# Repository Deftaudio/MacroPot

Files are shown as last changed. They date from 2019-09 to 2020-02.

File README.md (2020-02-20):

# MacroPot

Deftaudio MacroPot is a single knob deeply programable MIDI controller with extended interface capabilities based around Teensy HW and Arduino programming model. It's designed to be the most compact Teensy3.2 MIDI implementation in a very dense packaging inside a rugged enclosure. You don't need to be experienced in Arduino programming, it comes with full featured firmware. However for experienced users can leverage an Open Source firmware available for your own modifications.
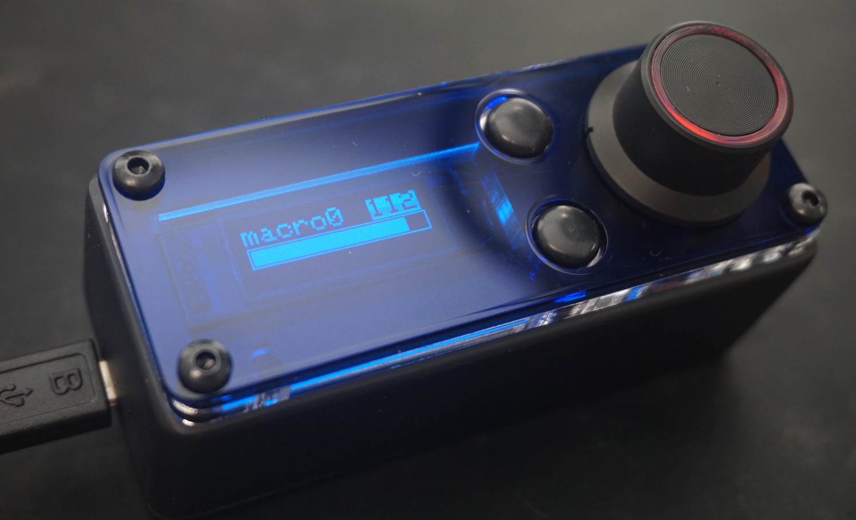
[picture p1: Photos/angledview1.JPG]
MacroPot assembled photo


### Introduction Video

https://youtu.be/noCOXES7csQ

### Hardware features:

- Rotary dual color (with brightness control) encoder with a push button

- OLED display for a visual feedback and preset information

- Up/Down buttons for a preset management

- 1 x MIDI Input (3.5mm TRS MIDI A or B)

- 3 x MIDI Output (3.5mm TRS MIDI A or B)

- USB MIDI Class compliant with 4 x MIDI devices under OS (1 physical port)

- 1 x Audio/CV/trigger/sync output (via PWM or DAC)

- Programmable activity LED

- Standalone operation from a power bank or power supply.

### Software features:

MacroPot is based around the idea of controlling multiple parameters at a time and quick switching between presets (macro). Within a current macro it’s possible to assign up to 5 simultaneous active controllers for transmit as well as a push button behavior. This allows to create layers or splits in values, assign controllers to different events, messages and MIDI ports, implement curves. MacroPot is also a 1x3 MIDI interface device with merging capability, which enables it at any place in the setup -- as a USB controller for any class compliant device or pass through HW MIDI input for your gear.

- **Number of Macros**:10

- **Number of controllers per Macro**:5

- **Controller parameters:**

	- USB output port number 1-4 to send a data out

	- MIDI port number 1-3 to send a data out

	- Type of the transmitted data: CC, Note, Program Change, Pitch Band (Synclavier mode), NRPN(future FW releases)

	- MIDI Channel 1-16

	- Programmable CC number, MIDI Note number or Program Change number

	- Controller range: Low value, High value

	- Controller mapping onto encoder position: Map start, Map end

	- Controller Curve for creating curves for CC messages

	- Programmable MIDI Note number for Note ON messages

- **Push Button parameters:**

	- USB output port number 1-4 to send a data out

	- MIDI port number 1-3 to send a data out

	- Type of the transmitted data: CC or Note

	- MIDI Channel 1-16

	- Programmable CC number or MIDI Note number

	- Programmable CC value or MIDI Note velocity

	- Different action behavior supported: Push button or Toggle(for Note)

- **MIDI Merge capability:** configurable per Macro HW MIDI input can pass through to any HW of 1-3 outputs

- **Assignable Macro name:** up to 7 characters on the display

- **Programming:** SysEx over USB

### Purchasing

MacroPot is an open project, you may decide to purchase a PCB only and source other parts by yourself with a BOM, get an electronic kit, a complete kit or go by pieces. There are multiple options for your level of experience and a budget.

- **MacroPot PCB only - $8**

- **MacroPot base electronic kit** (all electronics but Teensy 3.2): **- $38**

	- PCB

	- OLED

	- Encoder and a cap

	- Buttons and caps

	- Passive components - resistors, capacitors, diodes

	- Connectors - pin headers, 3.5mm TRS sockets

	- Dupont wires

- **MacroPot complete kit: - $68**

	- Base electronic kit

	- Teensy 3.2 (pre-programmed)

	- Enclosure *_(requires drilling and painting)_*

	- Acrylic panels

	- Rubber stands

	- Top screws

	- Thermal pad (TIM)
	
	- USB cable

- **MacroPot assembled unit - $118**

- **Spares:**

	- Acrylic Panels - $10

	- Transparent encoder cap - $5

	- Custom 3.5 mm mini stereo to 5 pin DIN MIDI breakout cable (male or female, Type A or Type B) - $7

#### **Available at:**

Tindie: https://www.tindie.com/stores/deftaudio/

- https://www.tindie.com/products/deftaudio/macropot-deeply-programmable-midi-controller-kit/

eBay: https://www.ebay.com/sch/ktracker_rus/m.html

- https://www.ebay.com/itm/333318502019
- https://www.ebay.com/itm/333318503584
- https://www.ebay.com/itm/333318504255
- https://www.ebay.com/itm/333318504975
- https://www.ebay.com/itm/333319417566
- https://www.ebay.com/itm/333319422143

### BOM list

https://docs.google.com/spreadsheets/d/15D16pYKxWzvwlihMUm6H49rWIW-DiubtF_ozgL0KMLI/edit?usp=sharing

### Assembly Guide

MacroPot is modular, you may decide that for particular project you don’t need all three MIDI outputs, or MIDI input, or Analog output and so you can omit some components. The schematic is open, you’re free to do that. Complete assembly process is documented in the guide and includes soldering, mechanical and programming steps.

https://docs.google.com/document/d/1nHQZJlmbKfMoiNE-2jQ2WAEOWn6yFhDtXKQVzbqB8Ts/edit?usp=sharing

**ASSEMBLY VIDEO:**

https://youtu.be/n0h99QKWodY

### Programming Guide

MacroPot is programmable over SysEX messages. There is no GUI editor currently, instead you just send a raw SysEx command with your favourite tool. I highly recommend cross-platform command line SendMIDI utility by Geert Bevin https://github.com/gbevin/SendMIDI but other tools, such as MIDIOX will work too.

SysEx programming may look confusing in a first place, in fact, you got great documentation to support your learning. You'll learn everything from here:

https://docs.google.com/document/d/1nPIYxyJ24XFE5UrgwzTidY-a2B3J3utPwMfMKG4Hb1w/edit?usp=sharing

**PROGRAMMING VIDEO:**

https://youtu.be/COOzS5v5v0I

**Synclavier Mode:**

https://youtu.be/EoEbT5Iu1uM

Andrei Kudryavtsev, Deftaudio 2008-2019.

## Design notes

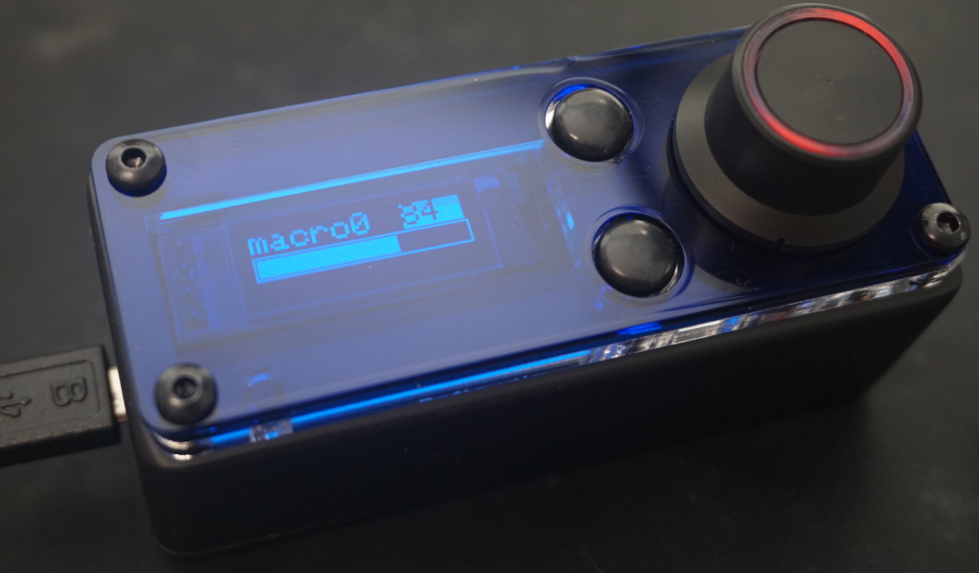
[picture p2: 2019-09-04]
Photos/angledview3.JPG

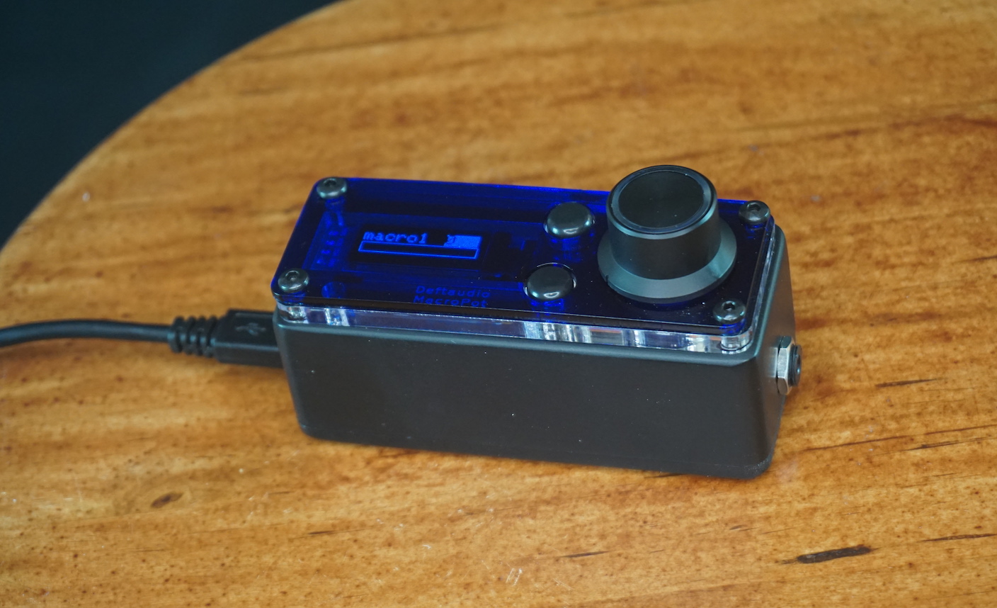
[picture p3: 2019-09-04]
Photos/faceview.JPG

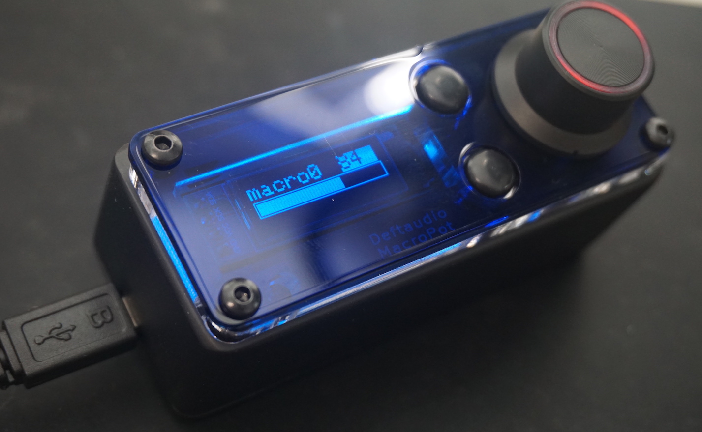
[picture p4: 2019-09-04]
Photos/angledview2.JPG

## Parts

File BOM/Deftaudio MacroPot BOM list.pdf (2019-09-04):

Deftaudio MacroPot BOM:
| P/N | Order from | Notes
U1 | 6N138 | https://www.mouser.com/ProductDetail/Broadcom-Avago/6N138-000E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 DIP package, install without a socket
U2 | Teensy 3.2 | https://www.pjrc.com/store/teensy32.html
D1 | 1N4148 | https://www.mouser.com/ProductDetail/ON-Semiconductor-Fairchild/1N4148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
D2 | 3mm LED | https://www.mouser.com/ProductDetail/Cree-Inc/C4SMA-BGF-CR2T3451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 Any standard 3mm LED, blue or other color
C1 | 10uf | https://www.mouser.com/ProductDetail/Nichicon/UVR1C100MDD1TD?qs=sGAEpiMZZMtZ1n0r9vR22WEPlYsslMWCGKrYlt2ZoWs%3D PWM audio output circuit, not required in case of DAC output
C2 | 103 0.01uf | https://www.mouser.com/ProductDetail/TDK/FG18X7R1H103KNT06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 PWM audio output circuit, not required in case of DAC output
C4, C5 | 103 0.01uf | https://www.mouser.com/ProductDetail/TDK/FG18X7R1H103KNT06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
C3 | 104 0.1uf | https://www.mouser.com/ProductDetail/TDK/FG16C0G1H104JNT06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
R1, R12, R17, R18 | 220 | https://www.mouser.com/ProductDetail/Xicon/271-220-RC?qs=t5KXG5YhMrJ%2F41luRETe6w%3D%3D
R2 | 100k | https://www.mouser.com/ProductDetail/Xicon/271-100K-RC?qs=sGAEpiMZZMu61qfTUdNhG8NgXDhdnsPdRkeci6KEHFY%3D PWM audio output circuit, not required in case of DAC output
R3 | 475 | https://www.mouser.com/ProductDetail/Xicon/271-475-RC?qs=sGAEpiMZZMu61qfTUdNhG3nVXymzmnYBdcdSbR9Z6RY%3D PWM audio output circuit, not required in case of DAC output
R4 | 127 | https://www.mouser.com/ProductDetail/Xicon/271-127-RC?qs=sGAEpiMZZMu61qfTUdNhGycWKXxEhBp7m%2F845gb5024%3D PWM audio output circuit, not required in case of DAC output
R5, R6, R7, R8, R9, R10 | 47 | https://www.mouser.com/ProductDetail/Xicon/271-47-RC?qs=sGAEpiMZZMu61qfTUdNhG%2Fx58qVkkJBr38p6bJPqRbo%3D
R11 | 470 | https://www.mouser.com/ProductDetail/Xicon/271-470-RC?qs=sGAEpiMZZMu61qfTUdNhG8zTzhjuYKP4eg8KQe8i%252Bpo%3D
R13, R14, R15, R16 | 10k | https://www.mouser.com/ProductDetail/Xicon/271-10K-RC?qs=sGAEpiMZZMu61qfTUdNhG%2FNICg4NOtz51bQLKR8aMJE%3D
Encoder with a switch | PEL12D-4226G-S2024 | https://www.mouser.com/ProductDetail/652-PEL12D4226GS2024 Burns dual color encoder
Encoder transparent cap | N/A | https://www.aliexpress.com/item/1652540985.html?spm=a2g0s.9042311.0.0.27424c4dnusFbH D-shaft type needed
OLED | 0.91" white/blue OLED 128X32 | https://www.ebay.com/itm/0-91-inch-128x32-IIC-I2C-Blue-OLED-Display-Module-DC3-3V-5V-128-32-Arduino/322536659354 Be careful, some OLED modules require longer init at least delay(1500)
Pin headers | 2.54mm pitch | https://www.ebay.com/itm/10-Pair-Male-Female-40Pin-2-54mm-Header-Socket-Single-Row-Strip-PCB-Connector-Us/153478821543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 Male and female, cut to the size where need
SW1, SW2 | push buttons | https://www.aliexpress.com/item/32804050454.html?spm=a2g0s.9042311.0.0.27424c4dVGao3M Square button with a round plastic cap
3.5mm jack | N/A | https://www.aliexpress.com/item/32954185700.html?spm=a2g0s.9042311.0.0.27424c4dnusFbH Plastic case with a metal screw
2 pin Dupont cable | N/A | https://www.aliexpress.com/item/32425641933.html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,searchweb201602_1,searchweb201603_52 You can cut them in half or assemble your own 2-pin cable with a separate headers
Enclosure | N/A | https://www.ebay.com/itm/1590A-Effects-Pedal-Aluminum-Stomp-Box-Enclosure-for-Musical-Instrument-Cases-WU/193045848734 Aluminum Stomp Box 9.2*3.8*3.2cm. Drilling and painting are required
Top acrylic panels | N/A | https://www.tindie.com/ | You can order from Tindie or make your own, design is open
PCB | N/A | https://www.tindie.com/

*eBay and Aliexpress links are for refference only. Pick your preferable supplier.

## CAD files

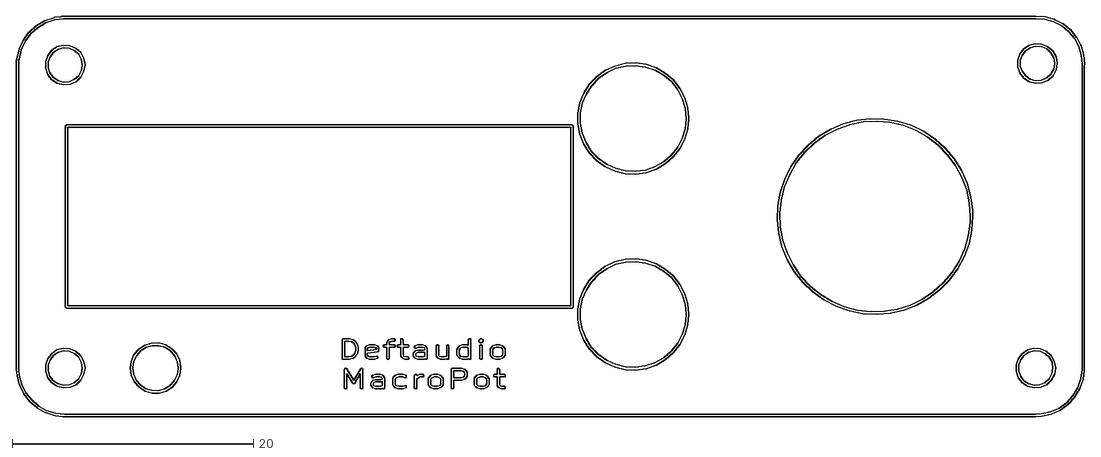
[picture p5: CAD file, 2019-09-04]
Acrylic panels/Middle layer/MacroPot-middle_4mm_clear_name.dxf
88.6 x 33.2

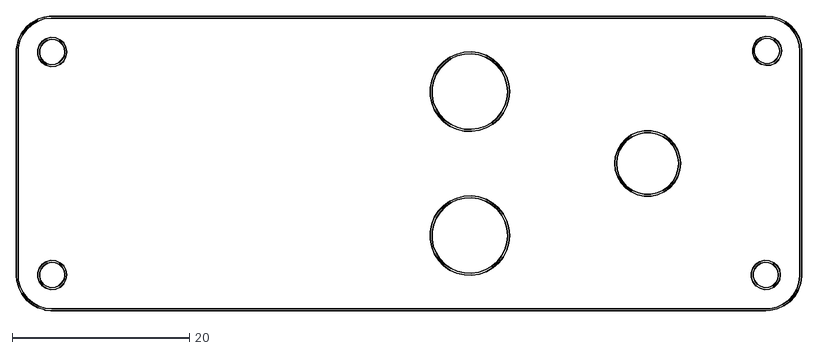
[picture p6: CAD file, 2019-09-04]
Acrylic panels/Top layer/MacroPot-top_1mm_blue.dxf
88.6 x 33.2

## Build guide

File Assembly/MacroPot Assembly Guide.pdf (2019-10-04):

# MacroPot Assembly Guide

The most recent version of this document is located here: https://docs.google.com/document/d/1nHQZJlmbKfMoiNE-2jQ2WAEOWn6yFhDtXKQVzbqB8Ts

MacroPot assembly process consists of three main steps. Electrical work - soldering all components, mechanical -
drilling an enclosure and painting, and initial firmware
initialization.
It may take upto an hour to finish the assembly (not counting a paint to dry) but depends on your level of experience. It’s
recommended that you solder a PCB first, and so you can test
the unit before assembling into the enclosure.

There is also a video version of this guide: https://youtu.be/n0h99QKWodY
Assembling a PCB.

This is a step where you can save some time, if you don’t use some of MacroPot functionality. For instance, you’re not planning to use PWM audio output or you don’t need all HW MIDI ports. You just don’t populate those parts and leave it empty.

Here are the components you may consider optional:
PWM audio output | R2, R3, R4, C1, C2, J2
HW MIDI input | R1, R11, D1, U1, C3, J1
HW MIDI output 1 | R5, R6, J3
HW MIDI output 2 | R9, R10, J5
HW MIDI output 3 | R7, R8, J4

Overall sequence doesn’t matter much, however, here are some recommendations to simplify the process, so soldering can be more convenient:

Andrei Kudryavtsev, Deftaudio 2008-2019.

1. Get familiar with the board design fist. Here are the front and back side of the board:

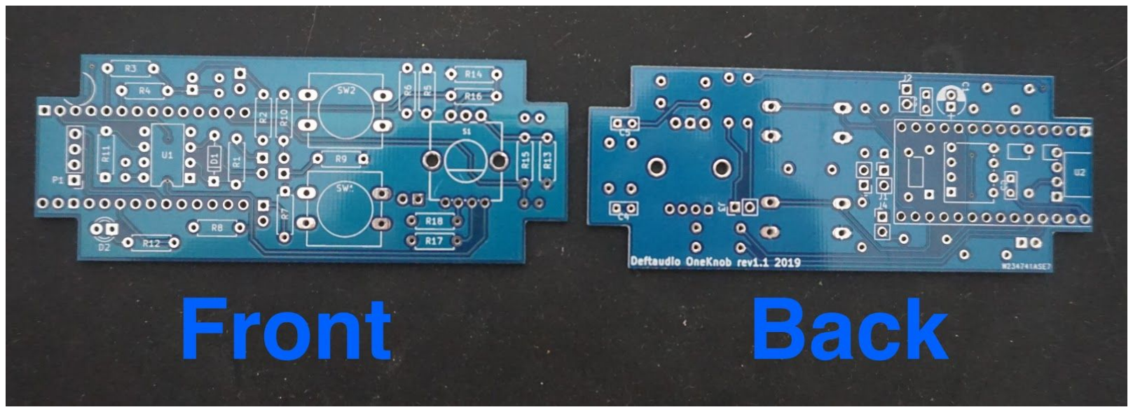
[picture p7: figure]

2. Decide on the functionality and components you need.
3. Start with soldering smaller parts first, such as resistors and diodes, so you lay the board on them and don’t need to hold them in a position.
4. Get to bigger components later, leave headers to the end.

### Soldering steps:

- Start with resistors on the front side and D1 diode. Those are:
D1 | 1N4148
R1, R12, R17, R18 | 220 ohm
R3(originally 475, 470 is Ok), R11 | 470 ohm
R13, R14, R15, R16 | 10k
R4(originally 127, 120 is Ok) | 120 ohm
R5, R6, R7, R8, R9, R10 | 47 ohm
R2 | 100k

- Add U1 (6N138) without socket (important) and two push buttons
- Flip the board over and populate capacitors on the back side. Those are:
C2, C4, C5 | 103 (0.01uf)
C3 | 104 (0.1uf)
C1 | 10uf

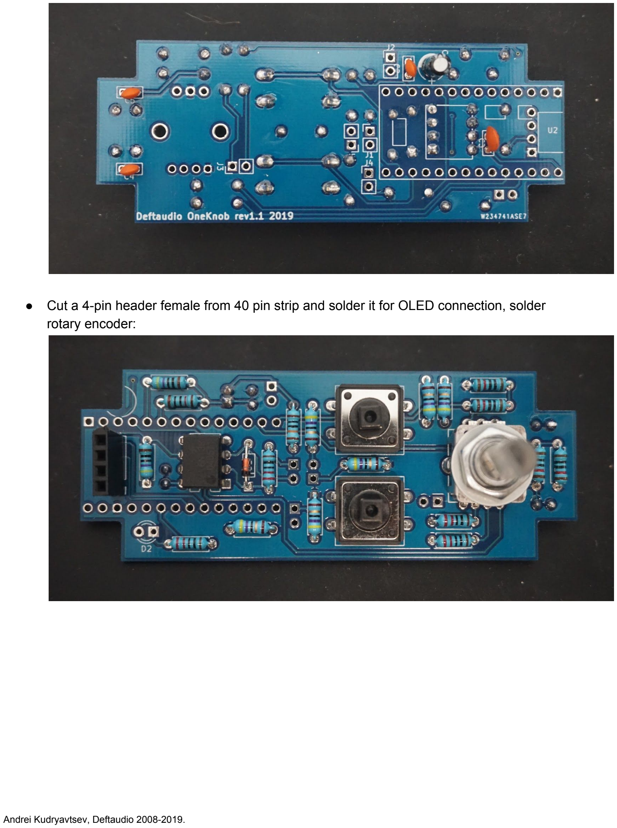
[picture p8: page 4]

- Cut a 4-pin header female from 40 pin strip and solder it for OLED connection, solder rotary encoder:

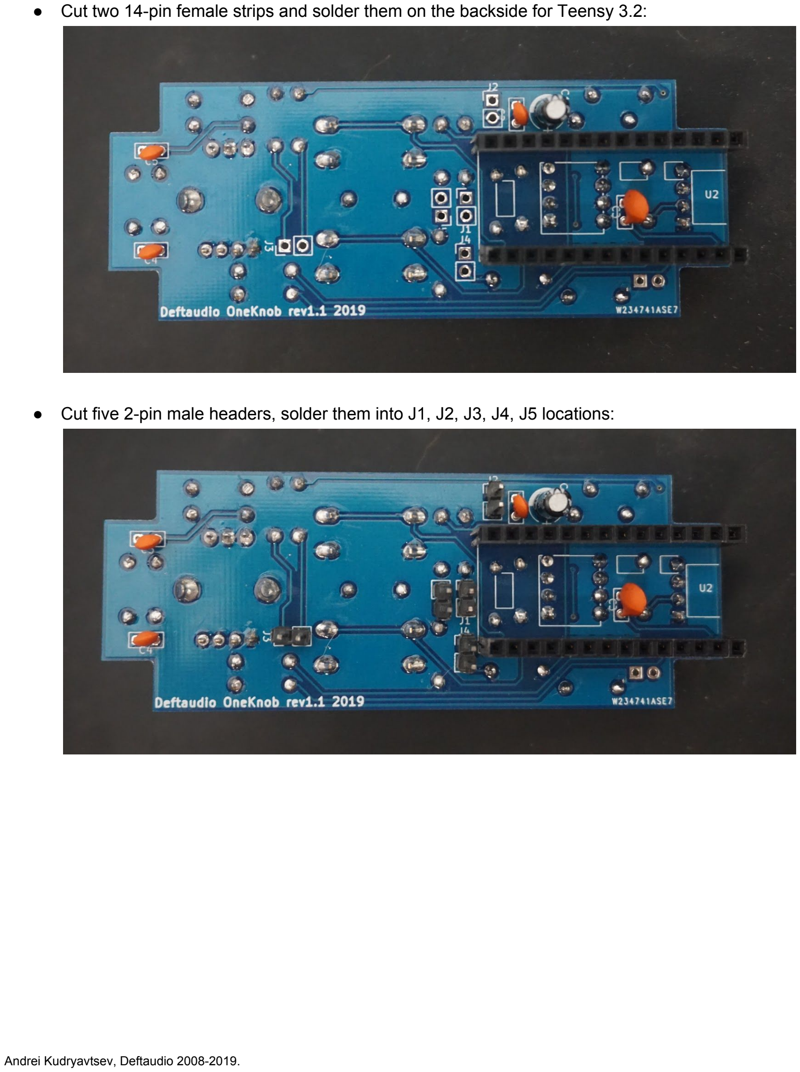
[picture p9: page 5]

- Cut two 14-pin female strips and solder them on the backside for Teensy 3.2:
- Cut five 2-pin male headers, solder them into J1, J2, J3, J4, J5 locations:

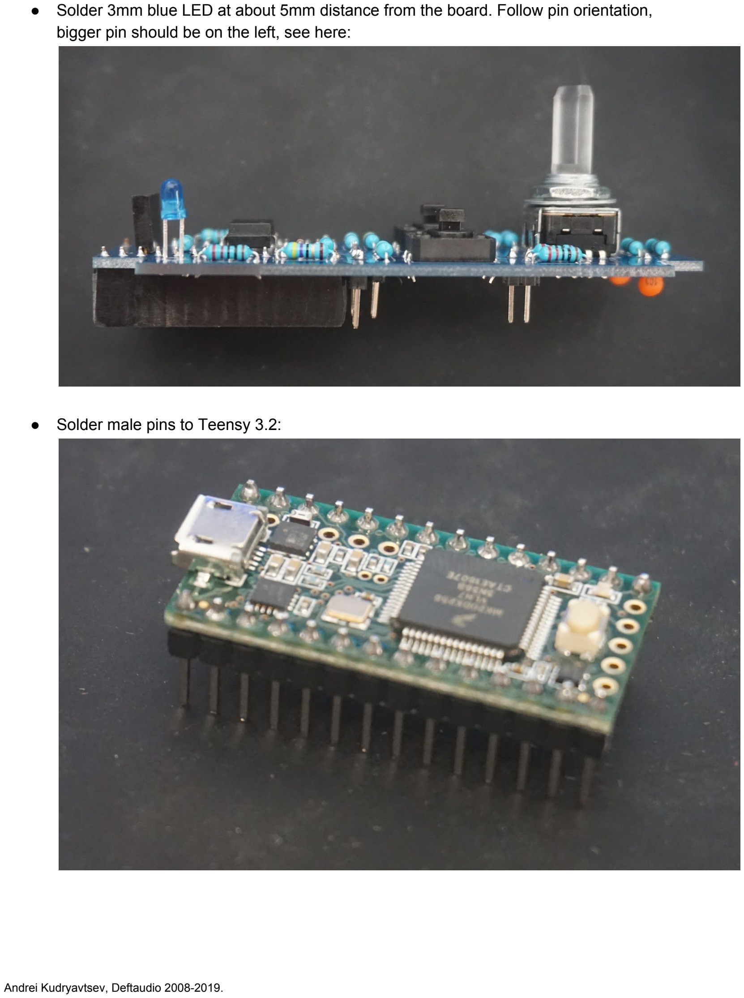
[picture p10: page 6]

- Solder 3mm blue LED at about 5mm distance from the board. Follow pin orientation, bigger pin should be on the left, see here:
- Solder male pins to Teensy 3.2:

Firmware initialization.

Right after you completed board soldering, it’s a good time to start MacroPot for the first time and make sure that at least basic functions are working fine. There are two stages in this process - updating firmware and loading default settings to Teensy’s EPROM.

### Updating a firmware from compiled *.hex file:

- If you’re experienced Arduino user, you may skip this part, it’s mainly for new users who are not familiar with Arduino programming or software development.
- *.hex file is a compiled binary, that you simply load to a Teensy board. That means, you don’t do any changes to the code by yourself, you just use what’s already available.
- While programming, Teensy can be assembled onto MacroPot board or just connected over USB without anything attached. This doesn’t matter. Obviously on the next power on it has to be attached to the board.

It’s important to understand that MacroPot saves macros and its state into nonvolatile memory (EPROM) of the Teensy controller. Main firmware image is only a program that runs on the controller. It doesn’t include any configuration parameters or pre-defined macroses. This is what needs to be configured after the firmware update. However, that’s also recommended to clean EPROM before updating main firmware, so, previous or garbage EPROM data won’t be used as macro configuration.

Steps:
- To start, download Teensy loader from official site: https://www.pjrc.com/teensy/loader.html
- Run it and drop eeprom_clear.hex firmware first from the MacroPot hex from the repository:
https://github.com/Deftaudio/MacroPot/blob/master/Firmware/eeprom_clear.hex
- Press button on Teensy and make sure loader app updated it.

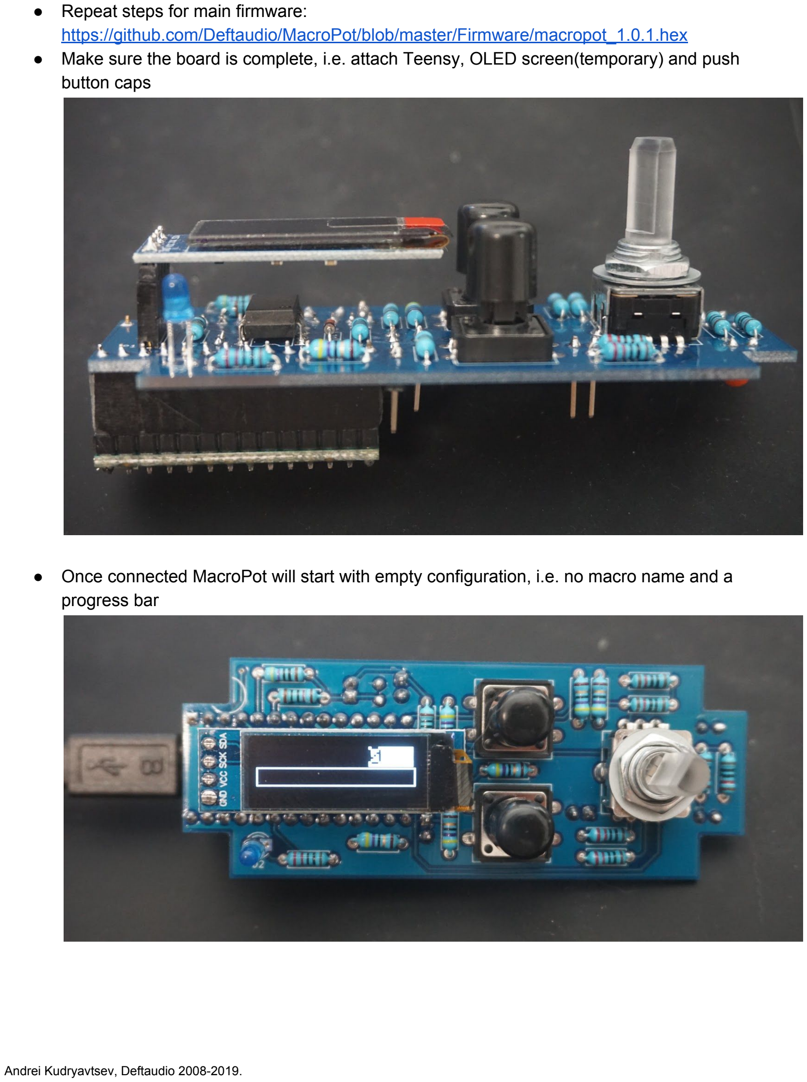
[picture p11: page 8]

- Repeat steps for main firmware: https://github.com/Deftaudio/MacroPot/blob/master/Firmware/macropot_1.0.1.hex
- Make sure the board is complete, i.e. attach Teensy, OLED screen(temporary) and push button caps
- Once connected MacroPot will start with empty configuration, i.e. no macro name and a progress bar

### Alternative: Updating a firmware from Arduino project:

- This step assumes that you take MacroPot source files, compile them and load to Teensy. It’s for experienced users how are willing to enhance MacroPot functions in future by contributing into the software development.
- Make sure you’re running latest Arduino version.
- Download and install Teensyduino: https://www.pjrc.com/teensy/td_download.html
- Open MacroPot project file.
- Set a controller to Teensy 3.2 in MIDIx4 mode.
- Set a running speed to 72Mhz, you don’t need to overclock Teensy for basic firmware.
- Compile and load eeprom_clear tutorial sketch following by the main firmware.

### Loading default macro configuration

MacroPot is deeply programmable controller over SysEx messages. However, to get you started, there are default scripts created to program its state. This minimizes your learning time, as default macroses designed to cover many common scenarios. Follow the download repository https://github.com/Deftaudio/MacroPot/tree/master/SysEx%20scripts you’ll find MS Windows and Mac OS X versions. They are designed to use cross-platform command line SendMIDI utility by Geert Bevin: https://github.com/gbevin/SendMIDI Just put a recent binary to the script directory first.

Here is an example of running SendMIDI under Windows,
- Run Command Line “cmd” and change a directory to the location of scripts:
- Connect MacroPot and execute “sendmidi list”. You’ll see all MIDI output devices connected to the system. As MacroPot has four virtual USB ports, there four separate devices below. You can use any of them for programming, but it’s easier to pick the first one due to a naming convention. Scripts do that by default.
- Press simultaneously Up and Down buttons on MacroPot controller, until “Sysex Mod” appears on the screen.
- Execute init.bat (Windows) or init.sh (OS X, don’t forget to make it executable first)

- Once script finishes, press Up button, now you should be able to see a default macro name:

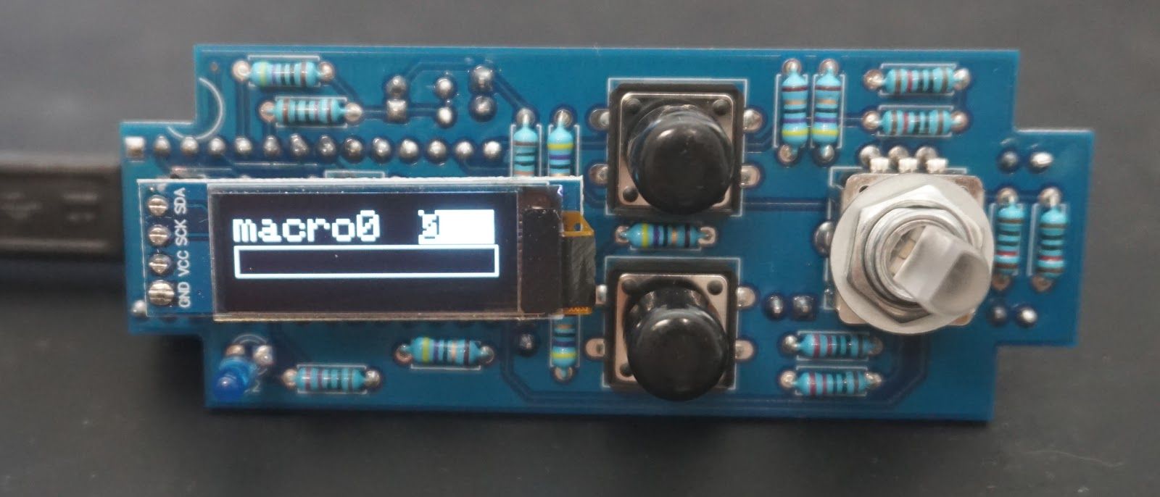
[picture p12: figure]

- At this point, you may run some basic tests, even without hardware MIDI ports connected. You may use MIDI OX or similar MIDI monitor sniffing USB MIDI traffic.

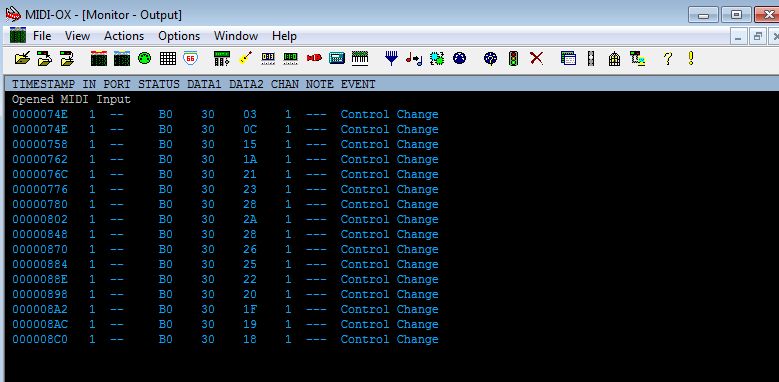
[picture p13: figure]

A note about TRS-DIN MIDI breakout cable.

At the time vendors decided to utilize TRS connectors for MIDI a common standard didn’t exist. So, every manufacturer went their own way, which basically introduced two standards, called Type A and Type B. Please,refer to MIDI.org article about that: https://www.midi.org/articles-old/updated-how-to-make-your-own-3-5mm-mini-stereo-trs-to-midi-5-pin-din-cables (https://www.midi.org/articles-old/updated-how-to-make-your-own-3-5mm-mini-stereo-trs-to-midi-5-pin-din-cables)

Type A assumes TRS tip is connected to Pin 5, and ring to Pin 4. While Type B specs has Pin 4 on a tip and ring on Pin 5. In both cases sleeve is the ground.

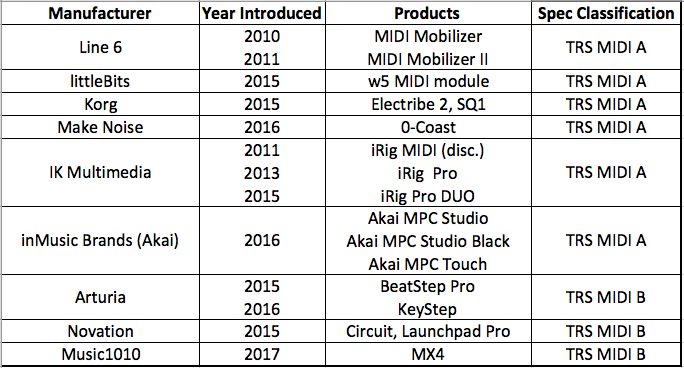
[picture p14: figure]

By the design MacroPot supports both types, all you need to do is to flip pin on a board header and so that changed tip/ring assignment. Ground pin is ignored, can be simply implemented by connecting it to the enclosure. Good news, that MIDI designed in a way, that even if you used the wrong polarity, this won’t burn the scheme. So, if port doesn’t work from the first attempt, flip the pin orientation and try again.

Connecting External Ports - MIDI and Audio.

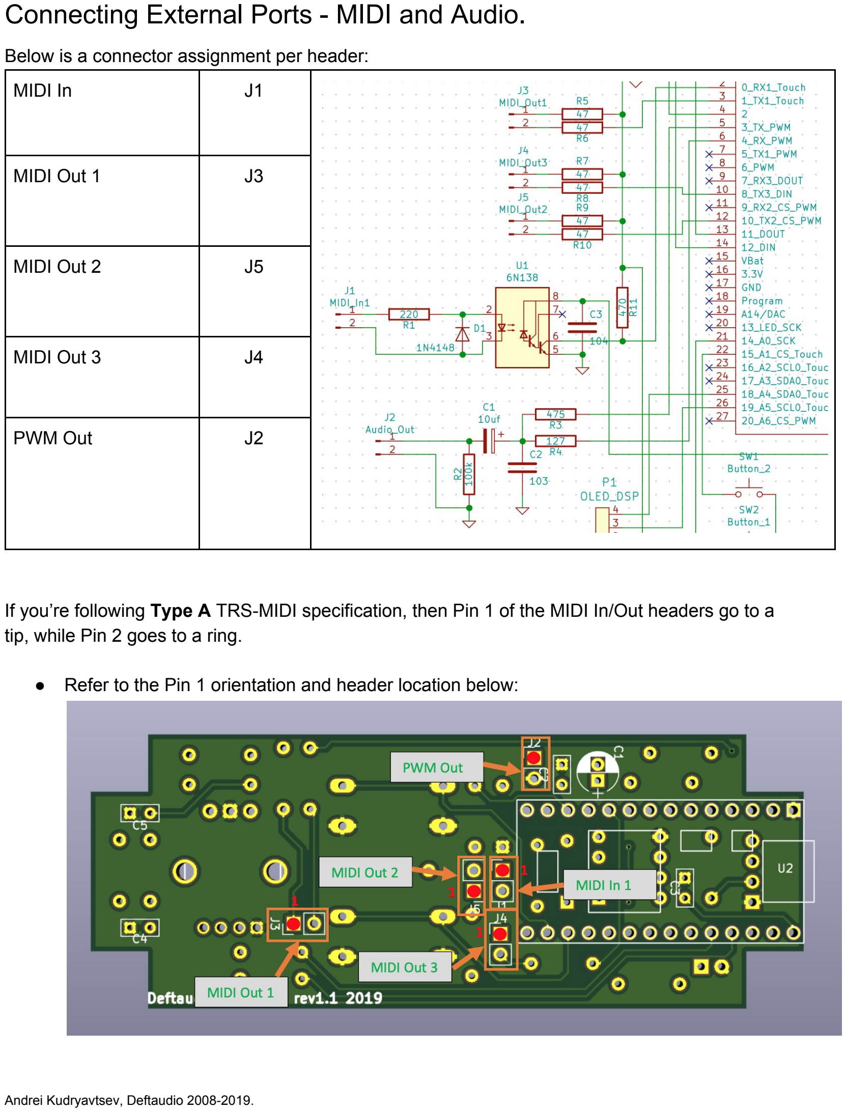
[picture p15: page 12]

Below is a connector assignment per header:
MIDI In | J1
MIDI Out 1 | J3
MIDI Out 2 | J5
MIDI Out 3 | J4
PWM Out | J2

If you’re following Type A TRS-MIDI specification, then Pin 1 of the MIDI In/Out headers go to a tip, while Pin 2 goes to a ring.

- Refer to the Pin 1 orientation and header location below:

- MIDI TRS socket orientation is shown below. On this connector type a ring is labeled #2 and tip is #3. Solder wires of different colors to differentiate them:

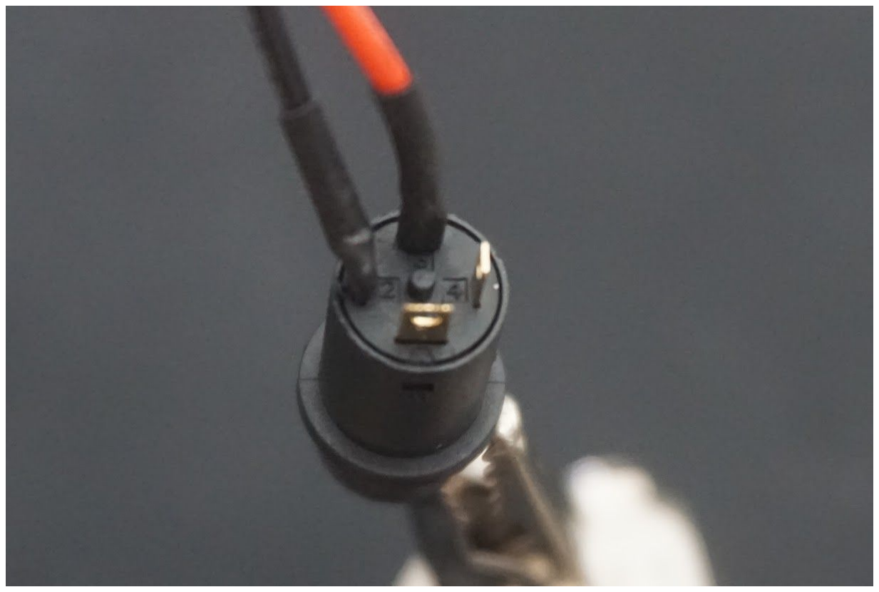
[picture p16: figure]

- So with that red wire means tip and black wire is for ring. Connect those accordingly to Type A or Type B specification to MacroPot headers.

Audio can be connected from two different places - PWM header output or DAC output. Those are differently programmed inside Teensy framework, you may prefer to use DAC output for better quality(12 bit) or even both of them together, if tip and ring pins utilized.
- In order to use DAC output you need to solder a wire directly to the pin shown below, as it’s not routed on the board to any headers.

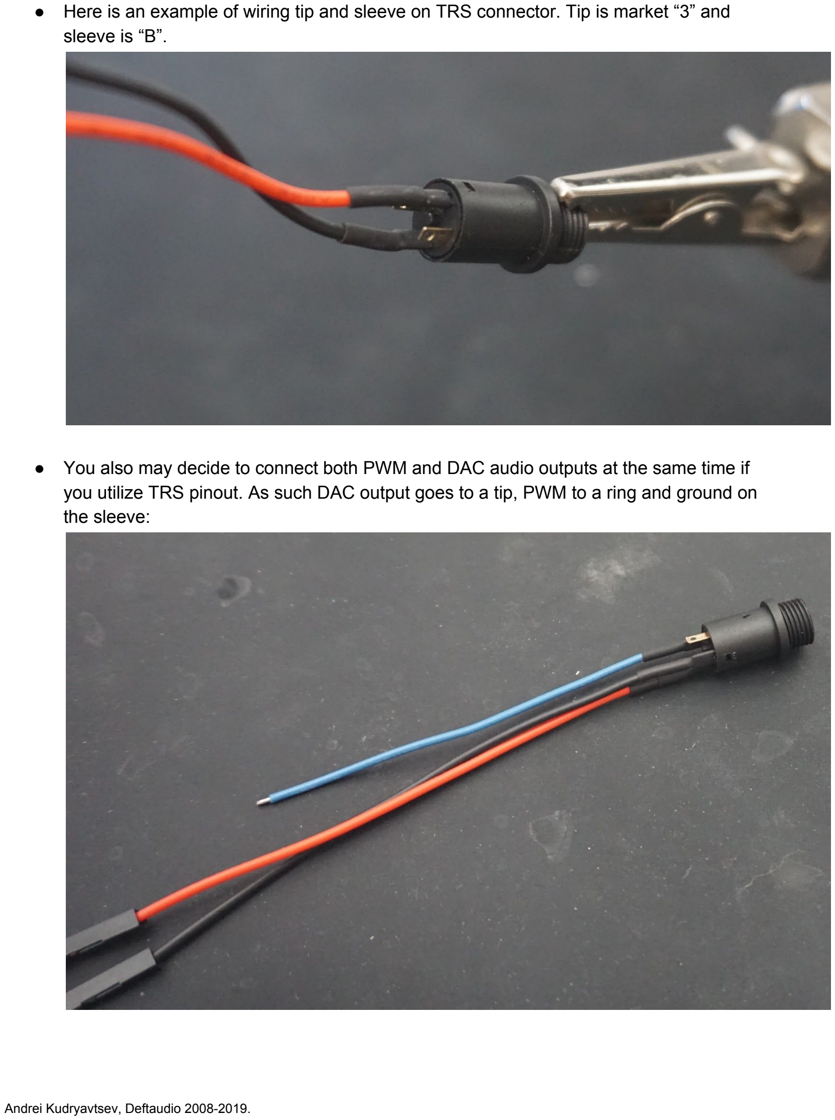
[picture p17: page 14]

- Here is an example of wiring tip and sleeve on TRS connector. Tip is market “3” and sleeve is “B”.
- You also may decide to connect both PWM and DAC audio outputs at the same time if you utilize TRS pinout. As such DAC output goes to a tip, PWM to a ring and ground on the sleeve:

Preparing an enclosure.

Preparing an enclosure requires drilling holes, making four threads and painting. You may decide to use a drill press or a hand drill. Core tool is highly recommended to make hole with a precision.
- Start by printing the draft label located here https://github.com/Deftaudio/MacroPot/blob/master/Acrylic%20panels/MacroPot-drill_alli gnment.pdf (https://github.com/Deftaudio/MacroPot/blob/master/Acrylic%20panels/MacroPot-drill_allignment.pdf) cutting it to the size and aligning to the enclosure:

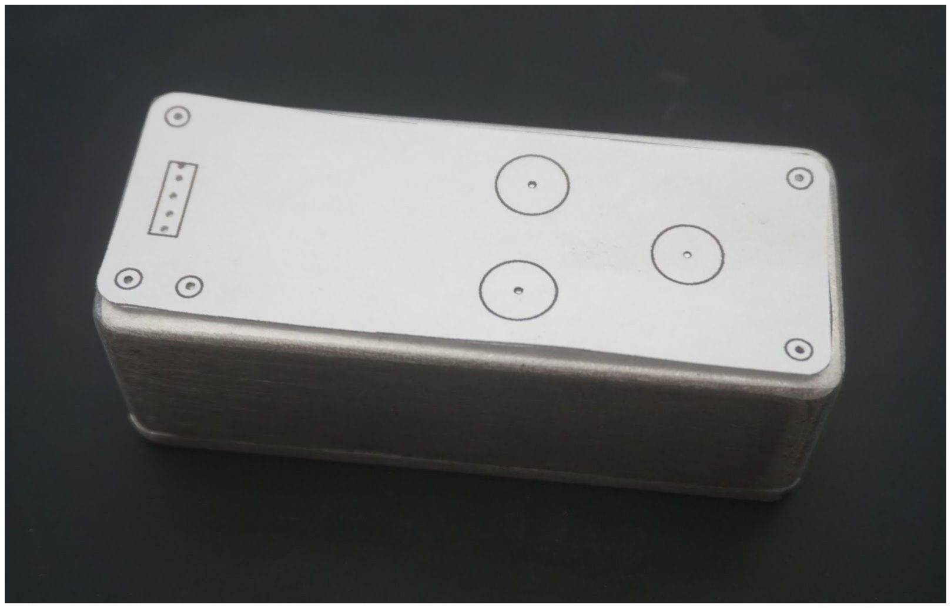
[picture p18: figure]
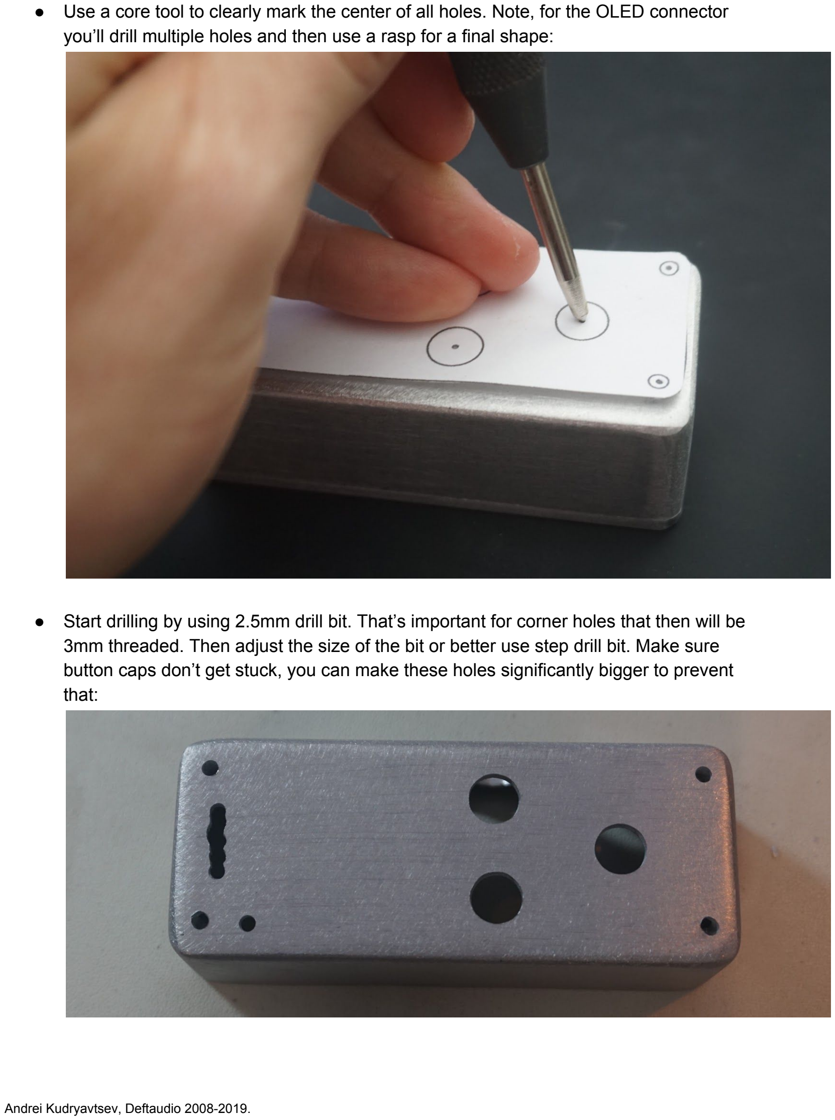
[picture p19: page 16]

- Use a core tool to clearly mark the center of all holes. Note, for the OLED connector you’ll drill multiple holes and then use a rasp for a final shape:
- Start drilling by using 2.5mm drill bit. That’s important for corner holes that then will be 3mm threaded. Then adjust the size of the bit or better use step drill bit. Make sure button caps don’t get stuck, you can make these holes significantly bigger to prevent that:

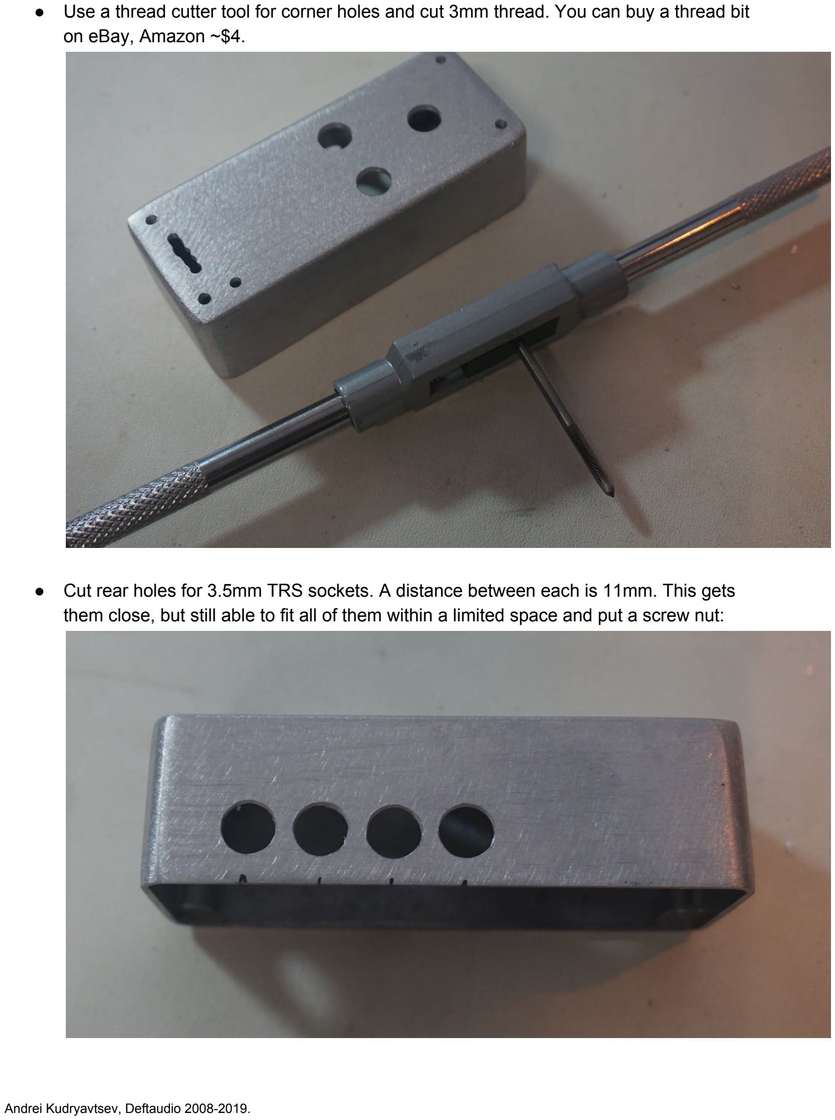
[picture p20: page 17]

- Use a thread cutter tool for corner holes and cut 3mm thread. You can buy a thread bit on eBay, Amazon ~$4.
- Cut rear holes for 3.5mm TRS sockets. A distance between each is 11mm. This gets them close, but still able to fit all of them within a limited space and put a screw nut:

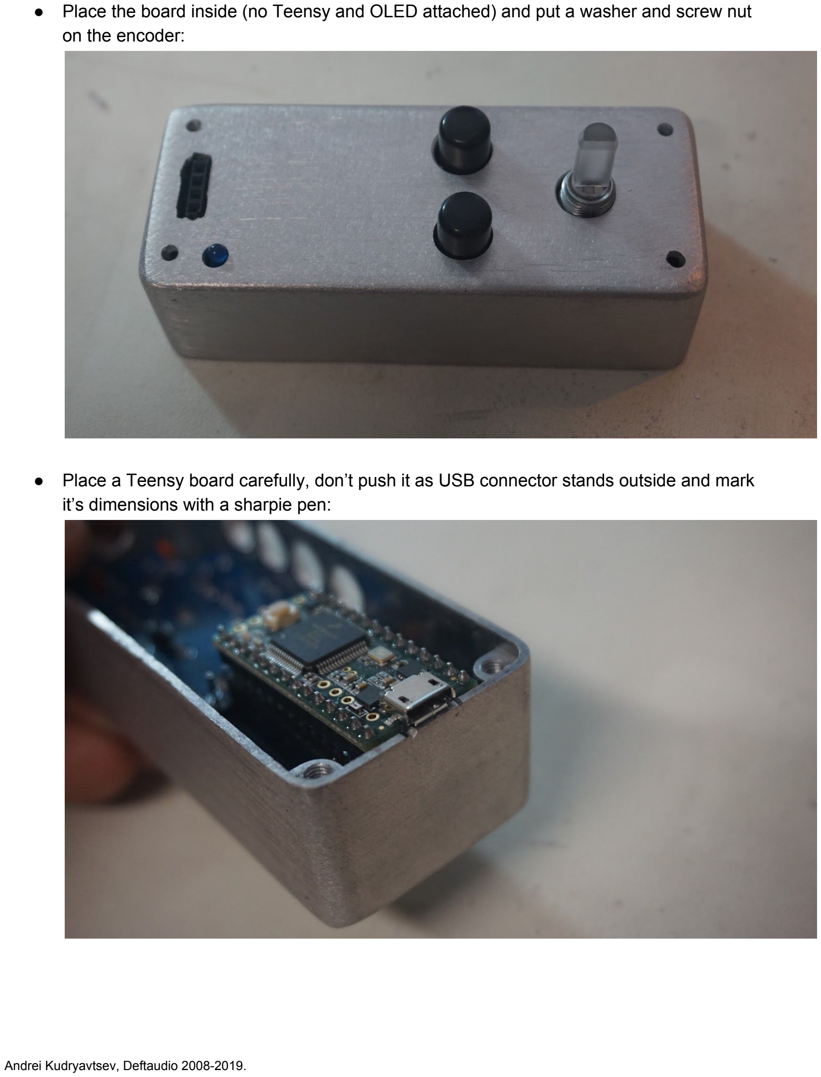
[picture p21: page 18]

- Place the board inside (no Teensy and OLED attached) and put a washer and screw nut on the encoder:
- Place a Teensy board carefully, don’t push it as USB connector stands outside and mark it’s dimensions with a sharpie pen:

- Use a rasp to get 2 mm inside, so microUSB connector stays flat.
- Place a bottom lid, mark with a sharpie tool again and use rasp to cut a piece there too:

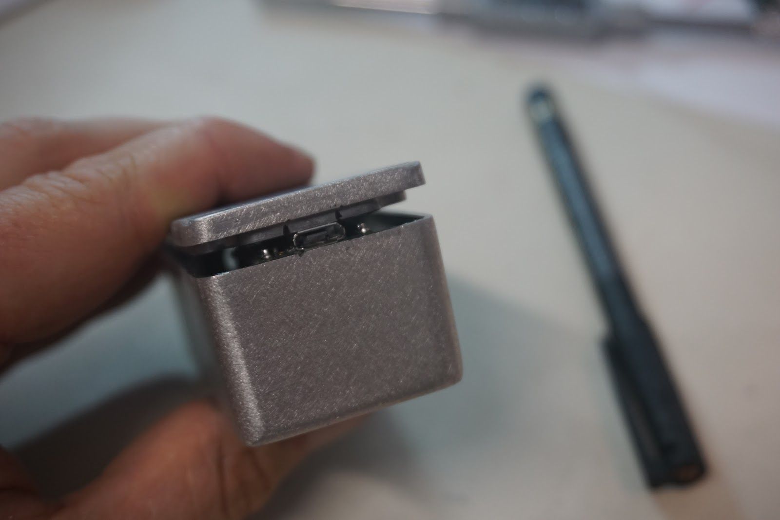
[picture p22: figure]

- Now it’s ready to be painted.

Final assembly.

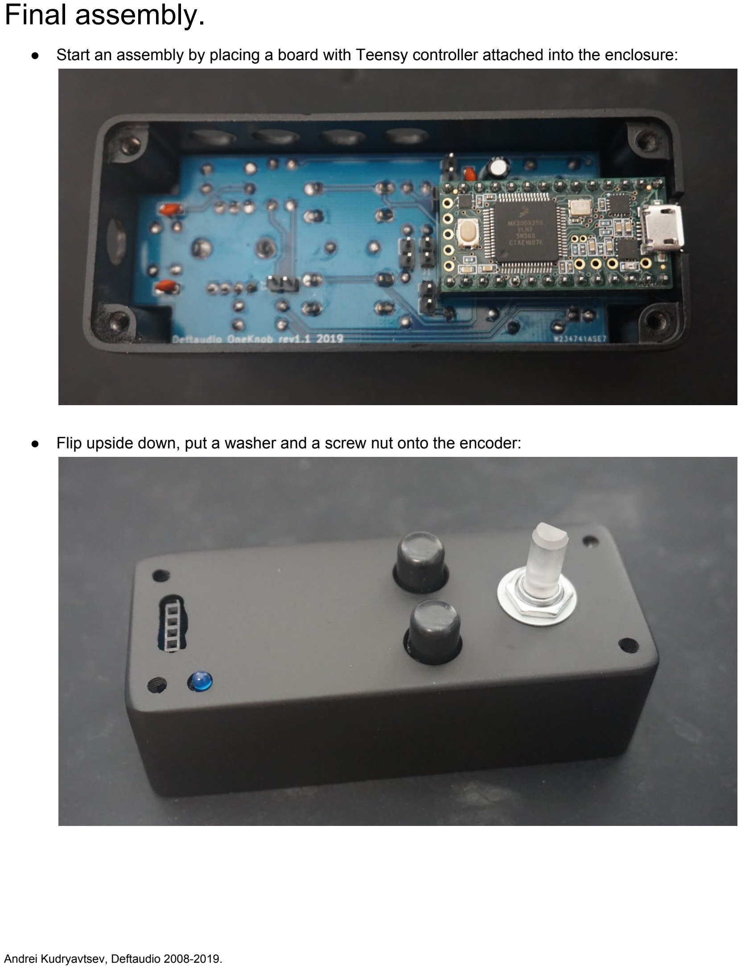
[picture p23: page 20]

- Start an assembly by placing a board with Teensy controller attached into the enclosure:
- Flip upside down, put a washer and a screw nut onto the encoder:

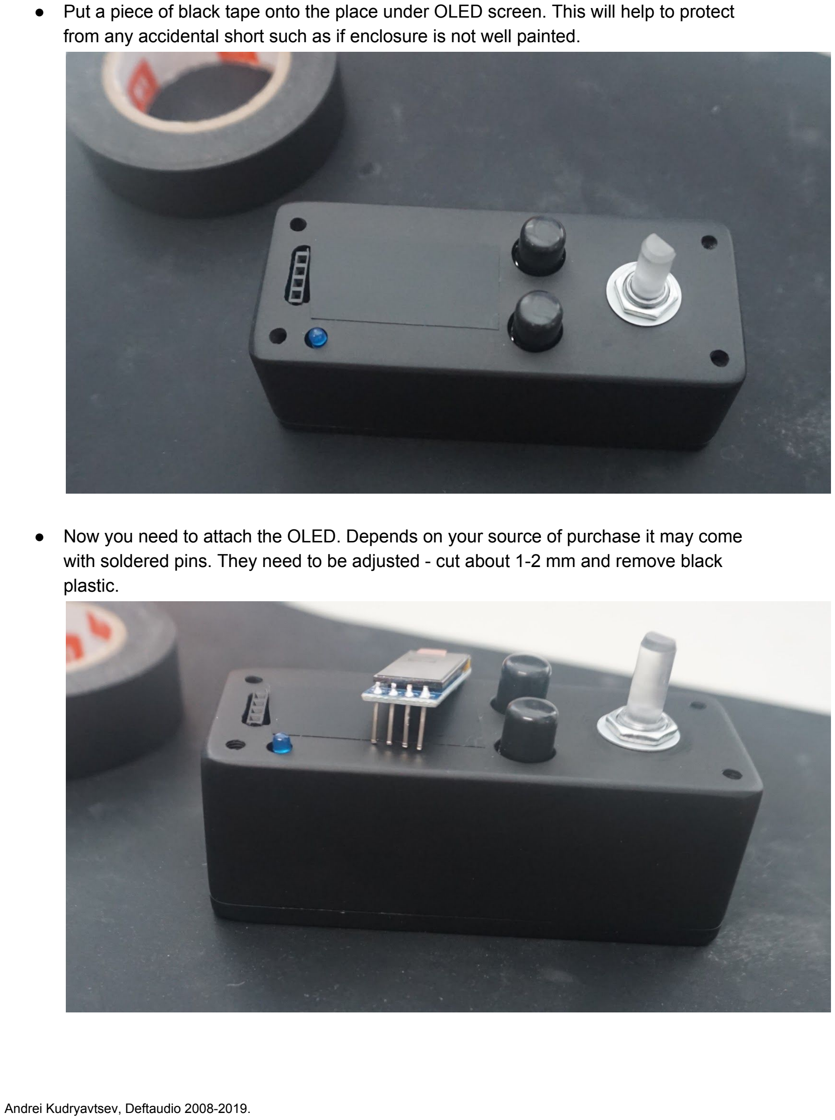
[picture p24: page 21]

- Put a piece of black tape onto the place under OLED screen. This will help to protect from any accidental short such as if enclosure is not well painted.
- Now you need to attach the OLED. Depends on your source of purchase it may come with soldered pins. They need to be adjusted - cut about 1-2 mm and remove black plastic.

- Note: Certain OLED displays require significantly longer initialization time (up to 2.6sec) before they can operate. You can identify those by the link below. Extra initialization latency can always be added into MacroPot firmware(cause longer time to start the unit) as well as “resistor mod” applied. However, would be better if you use the right model from the beginning.
http://torlus.com/floppy/forum/viewtopic.php?f=5&t=3240&p=17196#p17196
- Place OLED so it’s parallel to the enclosure and sits close to it:
- Quickly test the unit before proceeding to further assembly:

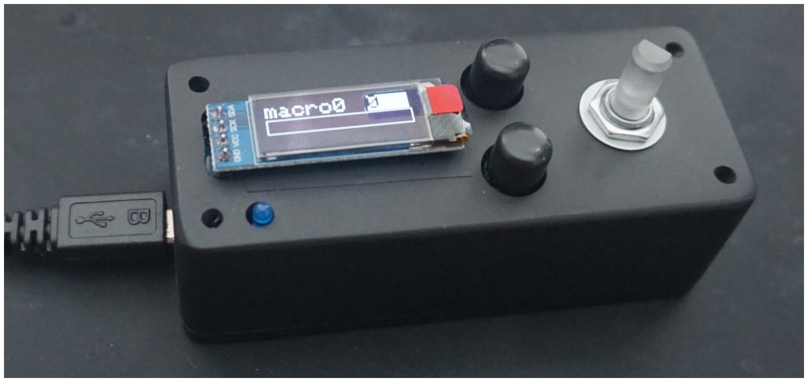
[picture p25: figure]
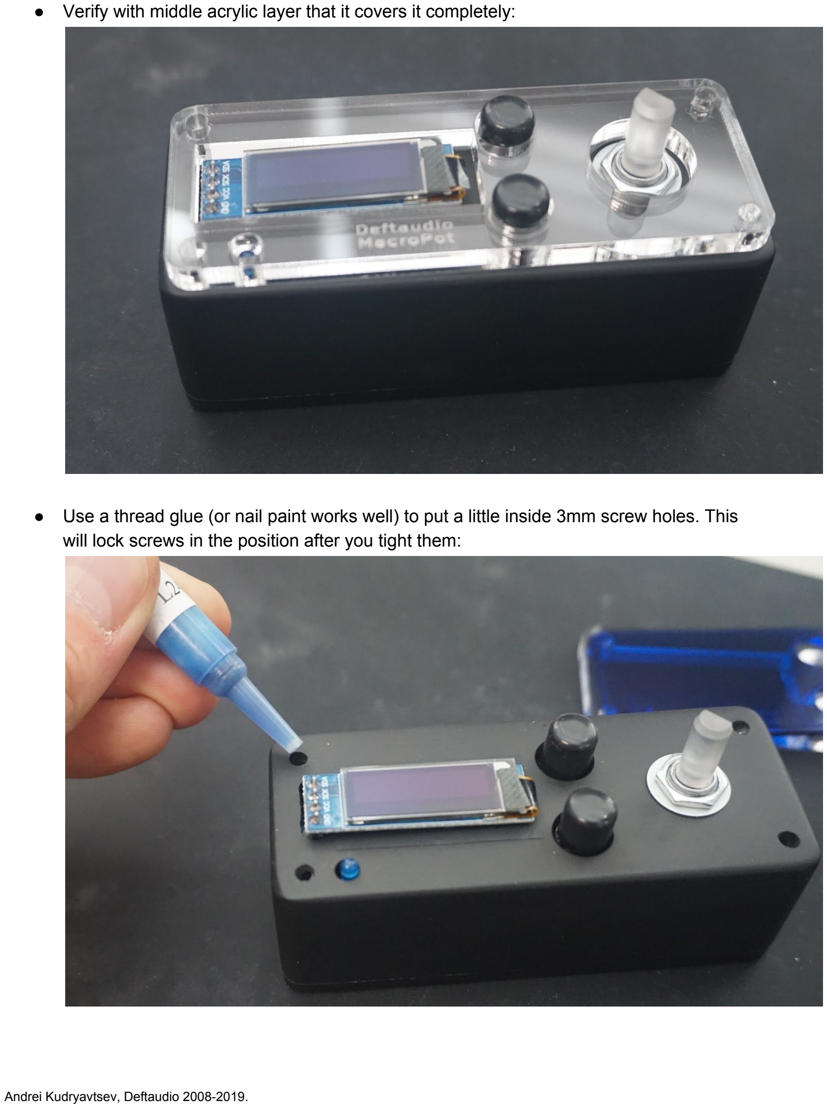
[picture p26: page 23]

- Verify with middle acrylic layer that it covers it completely:
- Use a thread glue (or nail paint works well) to put a little inside 3mm screw holes. This will lock screws in the position after you tight them:

- Place a middle layer and top acrylic layer, put the screws in but don’t tight them until you have all screws and align panels. Then carefully tighten all screws. Keep in mind that aluminium is a relatively soft material. Don’t over tight to avoid a thread damage.

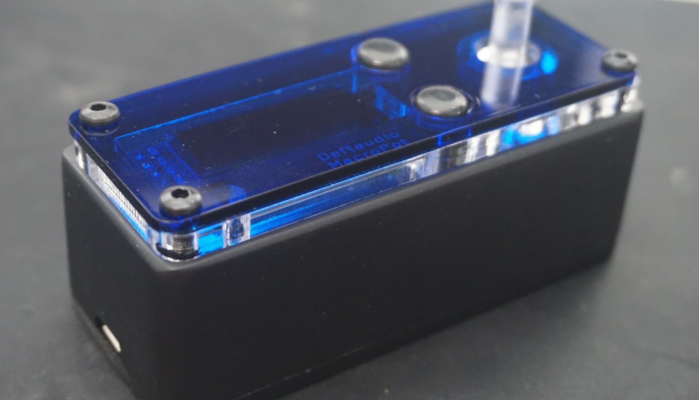
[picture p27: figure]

- Install all TRS connectors, starting MIDI connectors on the back side and audio out on the side. Connect per the diagram above and following desired TRS-MIDI Type A or B specification. The picture below is an example for Type A connection:

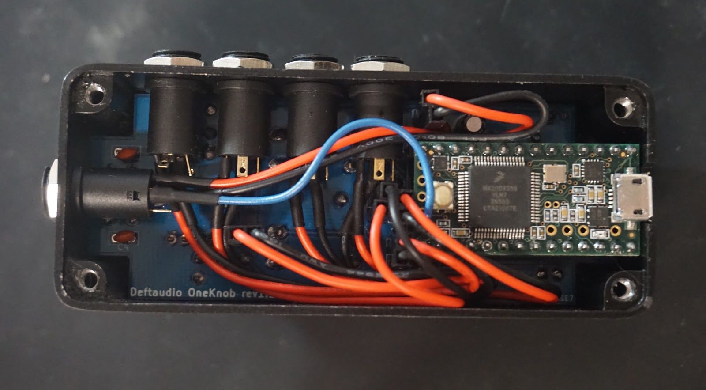
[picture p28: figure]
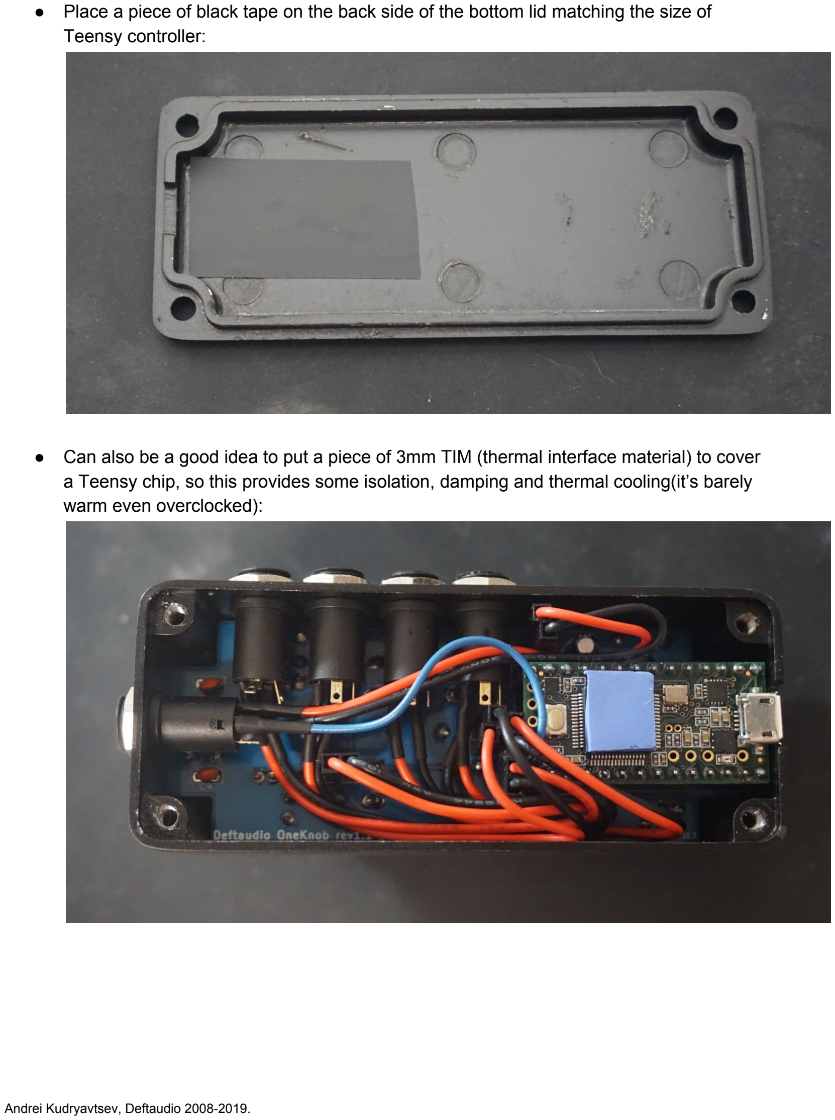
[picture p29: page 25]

- Place a piece of black tape on the back side of the bottom lid matching the size of Teensy controller:
- Can also be a good idea to put a piece of 3mm TIM (thermal interface material) to cover a Teensy chip, so this provides some isolation, damping and thermal cooling(it’s barely warm even overclocked):

- Place a bottom lid, tighten the screws and cover them with rubber pads:

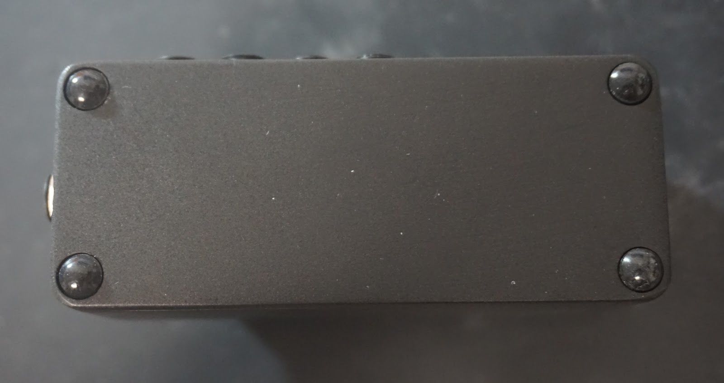
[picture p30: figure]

- Your device is complete. Feel free to start using it with some default macros, but shortly start learning a programming of this to explore all capabilities: https://docs.google.com/document/d/1nPIYxyJ24XFE5UrgwzTidY-a2B3J3utPwMfMKG4Hb1w/edit?usp=sharing (https://docs.google.com/document/d/1nPIYxyJ24XFE5UrgwzTidY-a2B3J3utPwMfMKG4Hb1w/edit?usp=sharing)

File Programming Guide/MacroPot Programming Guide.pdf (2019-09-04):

# MacroPot Programming Guide

The most recent version of this document is located here: https://docs.google.com/document/d/1nPIYxyJ24XFE5UrgwzTidY-a2B3J3utPwMfMKG4Hb1w/edit?usp=sharing

Please, note basic firmware update steps as well as default macro programming are covered in the Assembly Guide: https://docs.google.com/document/d/1nHQZJlmbKfMoiNE-2jQ2WAEOWn6yFhDtXKQVzbqB8Ts/edit?usp=sharing

Deftaudio MacroPot controller is multifunctional programmable MIDI controller based on the Teensy microcontroller. MacroPot firmware is open and available for your own modifications. This allows you to integrate it with Arduino environment and leverage community to expand and develop additional functionality.
All configuration of MacroPot parameters are done by using SysEx commands. There is no built in setup menu inside MacroPot, it’s designed to be simple to operate by switching pre-defined scenes or in this terms - Macros.

## Hardware features:

- Rotary dual color (with brightness control) encoder with a push button
- OLED display for a visual feedback and preset information
- Up/Down buttons for a preset management
- 1 x MIDI Input (3.5mm TRS MIDI A or B)
- 3 x MIDI Output (3.5mm TRS MIDI A or B)
- USB MIDI Class compliant with 4 x MIDI devices under OS (1 physical port)
- 1 x Audio/CV/trigger/sync output (via PWM or DAC)
- Programmable activity LED
- Standalone operation from a power bank or power supply.

## Software features:

MacroPot is based around the idea of controlling multiple parameters at a time and quick switching between presets (macro). Within a current macro it’s possible to assign up to 5 simultaneous active controllers for transmission as well as a push button behavior. This allows to create layers or splits in values, assign controllers to different events, messages and MIDI ports, implement curves. MacroPot is also a 1x3 MIDI interface device with merging capability, which enables it at any place in the setup — as a USB controller for any class compliant device or pass through HW MIDI input for your gear.

- Number of Macros: 10
- Number of controllers per Macro: 5
- Controller parameters:
- USB output port number 1-4 to send a data out
- MIDI port number 1-3 to send a data out

Andrei Kudryavtsev, Deftaudio 2008-2019.

- Type of the transmitted data: CC, Note, Program Change, Pitch Band (Synclavier mode), NRPN(future FW releases)
- MIDI Channel 1-16
- Programmable CC number, MIDI Note number or Program Change number
- Controller range: Low value, High value
- Controller mapping onto encoder position: Map start, Map end
- Controller Curve for creating curves for CC messages
- Programmable MIDI Note number for Note ON messages
- Push Button parameters:
- USB output port number 1-4 to send a data out
- MIDI port number 1-3 to send a data out
- Type of the transmitted data: CC or Note
- MIDI Channel 1-16
- Programmable CC number or MIDI Note number
- Programmable CC value or MIDI Note velocity
- Different action behavior supported: Push button or Toggle(for Note)
- MIDI Merge capability: configurable per Macro HW MIDI input can pass through to any HW of 1-3 outputs
- Assignable Macro name: up to 7 characters on the display
- Programming: SysEx over USB

## SysEx programming:

MacroPot programming is done under SysEx mode, which is a state where it can receive multiple SysEx configuration messages at a time, validate them and save into the non-volatile memory. To enter this mode UP and DOWN buttons have to be pressed simultaneously. There are multiple utilities that can generate and send SysEx commands, all examples below are using a cross-platform command line utility by Geert Bevin. https://github.com/gbevin/SendMIDI
This provides a readable output, easy to integrate into scripts. You should consider defaut scripts as the first start: https://github.com/Deftaudio/MacroPot/SysEx%20scripts/
In the meantime GUI editor development is ongoing and in future it will be available in addition to SendMIDI for programming MacroPot without dealing directly with HEX parameters.
As utility is cross-platform (Windows, OS X, Linux) all examples below will work without any change. Data is expected to be transmitted over USB MIDI port. Any of four ports can be used for that, but typically first port is easier for naming. Use “sendmidi list” to identify MacroPot first.

Default syntax for SendMIDI is following:
sendmidi dev "MacroPot Port 1" hex syx [sysex data here]

Note: You don’t need to specify F0/F7 start and closing bytes with SendMIDI utility. It always adds this on it’s own. So, only actual data starting from Dev ID (7D) is specified.

SysEx structure.

SysEx command structure replicates the software feature hierarchy. Programming is done in small chunks, where you select a feature to program (example Macro #1, Controller #1) and then specify its configuration settings. All parameters are translated in Hex, and so decimal values have to be converted first.

### All SysEx packages have a common structure:

Header | Dev ID | Macro number | Configuration subject | Configuration parameters | Footer
F0 - common for all Sysex Data | 7D - unique device ID, MacroPot uses 7D | [0-9] - a macro number for programming, ten in total, start with zero. | 0 - Push Button configuration [1-5] - for Controllers 1 to 5 64 - Global parameters per Macro | Specific to the configuration subject, no determined size. | F7 - common for all Sysex Data

All incoming SysEx data is verified for the data integrity by checking a closing byte F7 and matching the length of the SysEx package.

Note: You don’t need to do anything to save data into non-volatile memory, however it only saves after you exit SysEx mode (UP button) and switch a macro to any other. This provides an option to do multiple changes, validate parameters and only after that write it to a memory.

### Button Configuration:

F0 7D [macro#] 00 | [USBport#] | [MIDIport#] | [type] | [channel] | [number] | [value] | [push]
A header and macro # 0 to 9 | 0, 1 to 4 | 0, 1 to 3 | 0,1,2 | 1 to 0x10 | 0 to 0x7F | 0 to 0x7F | 0, 1

Description:

[USBport#] | USB 1-4 port # to send a data out, 0 means don't send to any of USB ports
[MIDIport#] | HW MIDI 1-3 port # to send a data out, 0 means don't send to any of MIDI ports
[type] | 0=Disabled, 1=CC, 2=Note
[channel] | MIDI Channel 1-16, hex 0x0 - 0x10
[number] | CC controller # or Note # depends on the [type] mode, see note to values chart

[value] | Velocity for Note ON messages or CC value
[push] | 1=push mode, 0=toggle for NOTE ON/OFF message

Note to values chart:

Octave | Notes
C | C# | D | D# | E | F | F# | G | G# | A | A# | B
0 | 0 | 1 | 2 | 3 | 4 | 5 | 6 | 7 | 8 | 9 | A | B
1 | C | D | E | F | 10 | 11 | 12 | 13 | 14 | 15 | 16 | 17
2 | 18 | 19 | 1A | 1B | 1C | 1D | 1E | 1F | 20 | 21 | 22 | 23
3 | 24 | 25 | 26 | 27 | 28 | 29 | 2A | 2B | 2C | 2D | 2E | 2F
4 | 30 | 31 | 32 | 33 | 34 | 35 | 36 | 37 | 38 | 39 | 3A | 3B
5 | 3C | 3D | 3E | 3F | 40 | 41 | 42 | 43 | 44 | 45 | 46 | 47
6 | 48 | 49 | 4A | 4B | 4C | 4D | 4E | 4F | 50 | 51 | 52 | 53
7 | 54 | 55 | 56 | 57 | 58 | 59 | 5A | 5B | 5C | 5D | 5E | 5F
8 | 60 | 61 | 62 | 63 | 64 | 65 | 66 | 67 | 68 | 69 | 6A | 6B
9 | 6C | 6D | 6E | 6F | 70 | 71 | 72 | 73 | 74 | 75 | 76 | 77
10 | 78 | 79 | 7A | 7B | 7C | 7D | 7E | 7F

Examples:
sendmidi dev "MacroPot Port 1" hex syx 7d [macro#] 00 [USBport#] [MIDIport#] [type] [channel] [number] [value] [push]

Macro 0 button programming, output to USB#1, HW MIDI #1, note C-4 push mode at ch1 sendmidi dev "MacroPot Port 1" hex syx 7d 00 00 01 01 02 01 30 7f 01

Macro 1 button programming, output to USB#1, HW MIDI #1, note C-4 toggle mode at ch1 sendmidi dev "MacroPot Port 1" hex syx 7d 01 00 01 01 02 01 30 7f 00

Macro 2 button programming, USB#1, HW MIDI #2, CC#48 (hex 30) push mode at ch1 sendmidi dev "MacroPot Port 1" hex syx 7d 02 00 01 02 01 01 30 7f 01

Macro 3 button programming, USB#2, NO HW MIDI, CC#48 toggle mode at ch1 sendmidi dev "MacroPot Port 1" hex syx 7d 03 00 02 00 01 01 30 7f 00

### Controller Configuration:

F0 7D [macro#] | [controller#] | [USBport#] | [MIDIport#] | [type] | [channel] | [number]
A header and macro # 0 to 9 | 1 to 5 | 0, 1 to 4 | 0, 1 to 3 | 0,1,2,3 , 5 | 1 to 16 | 0 to 0x7F
[lowvalue] | [highvalue] | [mapstart] | [mapend] | [curve] | [velocity]
0 to 5 | 0, 1 to 4 | 0, 1 to 3 | 0,1,2,3, 5 | 1 to 0x10 | 0 to 0x7F

Description:

[controller#] | A controller for editing, one at a time
[USBport#] | USB 1-4 port # to send a data out, 0 means don't send to any of USB ports
[MIDIport#] | HW MIDI 1-3 port # to send a data out, 0 means don't send to any of MIDI ports
[type] | 0=Disabled, 1=CC, 2=Note, 3=Program Change, 4=NRPN(to be implemented), 5=SynclavierMODE(can be the only in a macro, see a section)
[channel] | MIDI Channel 1-16, hex 0x0 - 0x10
[number] | CC controller #, Note # or Program Change # depends on the [type] mode
[lowvalue] | Low Value for CC range or main value for Note messages
[highvalue] | High Value for CC range, ignored if the type is Note
[mapstart] | Start position for mapped range in CC mode, main value for Note mode
[mapend] | End position for mapped range in CC mode, ignored if the type is Note
[curve] | For creating curves for CC messages deviation middle position is 0x40 have to be set for default
[velocity] | Velocity for Note ON messages

Note: NRPN mode to be implemented in future releases. Synclavier mode is covered in another section.

Understanding of CC ranges and mapping.

MacroPot is capable to produce multiple MIDI messages at the same type for a defined encoder move. That’s called a controller. There are up to 5 controllers per macro that can send
messages such as Control Changes, Notes, or Program Changes. They are very flexible but some configuration parameters may look confusing as they are unique to MacroPot. The illustration below is made to simplify this:

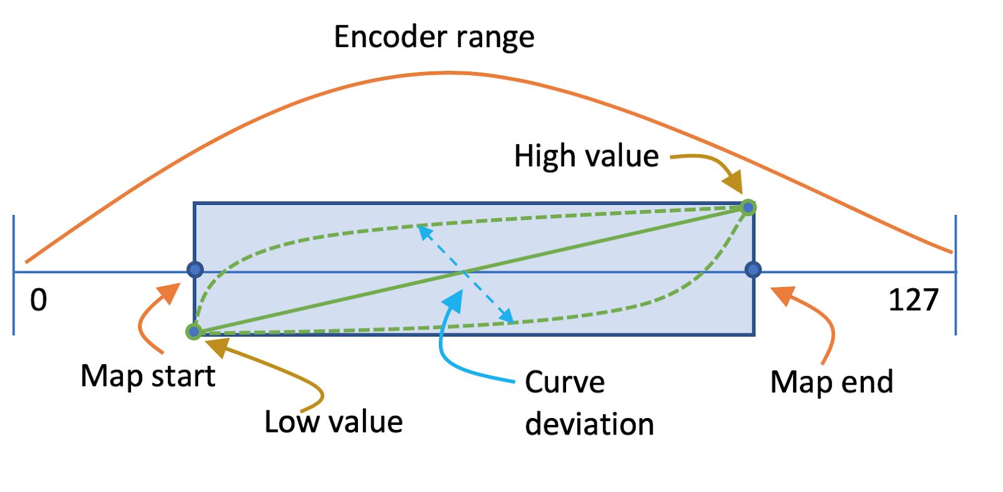
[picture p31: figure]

Consider whole encoder range from 0 to 127 (or 0x7F in hex). Within this range you can map a controller with Map Start, Map End, Low Value and High Value parameters. Map Start determines where controller is triggered with Low Value and it goes by some curve until it reaches Map End and it’s where it has the maximum defined value - High Value. Curve Deviation (very similar to Velocity Curves in MIDI keyboards) is how linear its function. In the middle parameter (0x40) it’s exactly linear, while going to upper or lower create a response shown on a chart.

As Map Start/End and Low/High Value parameters are per Controller, that allows to create overlapping controllers with different values and distributions weight. You also may decide to split the whole range between controllers or create fade effect between them by shaping curves and other parameters. Controller values can also be decrementing, so it starts high to goes down. This can be useful for some parameters such as envelope attack, where for instance you want to open a filter for staccato sounds.

Your imagination is the only limit.

Examples:
sendmidi dev "MacroPot Port 1" hex syx 7d [macro#] [controller# 1-5] [USBport#] [MIDIport#] [type] [channel] [number] [lowvalue] [highvalue] [mapstart] [mapend] [curve] [velocity]

Macro 0 controller 1 programming, output to USB#1, HW MIDI #1, CC #48 (0x30) starts from 0 to 127 (0x7F) with a range from 0 to 127 (0x7F). (Basically maps an encoder 1:1 on a complete range.)
sendmidi dev "MacroPot Port 1" hex syx 7d 00 01 01 01 01 01 30 00 7f 00 7f 40 7f

Macro 1 program controllers 1 to 4 from 0 to 127 (0x7F) all range to ALL USB and MIDI ports
sendmidi dev "MacroPot Port 1" hex syx 7d 01 01 01 01 01 01 30 00 7f 00 7f 40 7f sendmidi dev "MacroPot Port 1" hex syx 7d 01 02 02 03 01 01 31 00 7f 00 7f 40 7f sendmidi dev "MacroPot Port 1" hex syx 7d 01 03 03 03 01 01 32 00 7f 00 7f 40 7f sendmidi dev "MacroPot Port 1" hex syx 7d 01 04 04 04 01 01 33 00 7f 00 7f 40 7f

Note: Updating one controller doesn’t erase settings of another controller. There are some conditions where you want simply disable a controller, such as in the example below for controller #5:
sendmidi dev "MacroPot Port 1" hex syx 7d 01 05 01 01 00 01 00 00 7f 00 7f 40 7f

Macro 1 program split controllers 1 and 2, where controller 1 goes from 0 to 127(0x7F) on the range 0 to 64(0x40) and controller 2 goes from 0 to 127(0x7F) on the range 65(0x41) to 127 (0x7F).
sendmidi dev "MacroPot Port 1" hex syx 7d 02 01 01 01 01 01 30 00 7f 00 40 40 7f
sendmidi dev "MacroPot Port 1" hex syx 7d 02 01 01 03 01 01 31 00 7f 41 7f 40 7f

Macro 3 program controllers 1 and 2 from 0 to 127(0x7F) on 1 and 2 USB and MIDI ports, while Note message is sent to port 3 and the end of the range
sendmidi dev "MacroPot Port 1" hex syx 7d 03 01 01 01 01 01 30 00 7f 00 7f 40 7f
sendmidi dev "MacroPot Port 1" hex syx 7d 03 02 02 02 01 01 31 00 7f 00 7f 40 7f
sendmidi dev "MacroPot Port 1" hex syx 7d 03 03 03 03 02 01 00 00 7f 7e 7f 40 7f

Macro 4 program controller 1 and 2 from 0 to 127(0x7F) for CC#48 (0x30) and CC#49 (0x31) on 1 and 2 USB and MIDI ports, adds a Curve on controller 2, while Program Change #64 message is sent to port 3 at the end of the range
sendmidi dev "MacroPot Port 1" hex syx 7d 04 01 01 01 01 01 30 00 7f 00 7f 40 7f sendmidi dev "MacroPot Port 1" hex syx 7d 04 02 02 02 01 01 31 00 7f 00 7f 7f 7f sendmidi dev "MacroPot Port 1" hex syx 7d 04 03 03 03 03 01 40 00 7f 70 7f 40 7f

Synclavier Mode.

It’s a special mode designed to integrate MacroPot into Synclavier Pocket or GO iOS applications. The app expects to receive a pitchband information and change a parameter value to applied move of the pitchband wheel. MacroPot doesn’t have a spring that returns an encoder to the zero position such as an original ORK or VPK keyboard or newer Synclavier controller. Instead of that it translates the speed of the encoder movement to the pitch band value. So while user rotates the encoder it changes a value at the rate of the rotation speed and direction.
As Synclavier mode is such a special, there is no start or end of the encoder values, it’s only possible to run it alone within a macro and can’t be combined with other controllers.

Example:
sendmidi dev "MacroPot Port 1" hex syx 7d [macro#] [controller# 1-5] [USBport#] [MIDIport#] [type] [channel] [number] [lowvalue] [highvalue] [mapstart] [mapend] [curve] [velocity]

Macro 9 Synclavier mode enabled on USB port 2. Other controllers to be erased. sendmidi dev "MacroPot Port 1" hex syx 7d 09 01 02 00 05 01 00 00 7f 00 7f 40 7f sendmidi dev "MacroPot Port 1" hex syx 7d 09 02 01 01 00 01 00 00 7f 00 7f 40 7f sendmidi dev "MacroPot Port 1" hex syx 7d 09 03 01 01 00 01 00 00 7f 00 7f 40 7f
sendmidi dev "MacroPot Port 1" hex syx 7d 09 04 01 01 00 01 00 00 7f 00 7f 40 7f
sendmidi dev "MacroPot Port 1" hex syx 7d 09 05 01 01 00 01 00 00 7f 00 7f 40 7f

Note. Non related parameters such as Map start/end, Low/High value are ignored but they have to be specified for the consistency of the SysEx message size.

### Macro Configuration:

F0 7D [macro#] | MacroName [7] | MidiThru
A header and macro # 0 to 9 | 7 x ASCII characters | 0 - 7

Description:

MacroName [7] | is a 7 byte sequence of the macro name which represents seven ASCII characters. It’s convenient to use online tools to translate Text to Hex: https://online-toolz.com/tools/text-hex-convertor.php You’ll need to separate the output by each ASCII code.
MidiThru | A binary code that determines if HW MIDI input is forwarded to one of the MIDI outputs. It’s designed to work as per table below.

By default all the data that comes to MIDI Input is forwarded to USB Port 1 as well as all data from USB ports 1-3 is forwarded to MIDI Out 1-3. This allows using MacroPot as a MIDI interface. However there are situations, where MacroPot preferably to stay in the middle of the MIDI chain, such as working in standalone mode in front of the MIDI gear or synthesizer. For that you may decide to forward all incoming MIDI data from the input to one or many output ports:

MidiMerge value | Binary code | Description
0 | 000 | No MIDI thru
1 | 001 | MIDI In forwarded to Port 1
2 | 010 | MIDI In forwarded to Port 2
3 | 011 | MIDI In forwarded to Port 1 and 2
4 | 100 | MIDI In forwarded to Port 3
5 | 101 | MIDI In forwarded to Port 1 and 3
6 | 110 | MIDI In forwarded to Port 2 and 3
7 | 111 | MIDI In forwarded to all three ports

Examples:

Macro 5 forward MIDI Input to MIDI Output port 1 and change the name to "Merge" (6d 65 72 67 65 20 20 in hex)
sendmidi dev "MacroPot Port 1" hex syx 7d 05 64 6d 65 72 67 65 20 20 01

Macro 6 orward MIDI Input to all MIDI Output ports and change the name to "MergALL" (4d 65 72 67 41 6c 6c)
sendmidi dev "MacroPot Port 1" hex syx 7d 06 64 4d 65 72 67 41 6c 6c 07

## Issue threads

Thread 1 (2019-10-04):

Documentation has dead links

Cabalist, 2019-10-04:
Hey there,

Just building this and noticed that there are a number of places in the documentation with links that point to the incorrect places:

For instance:

pg 15:
> Start by printing the draft label located here https://github.com/Deftaudio/MacroPot/Acrylic%20panels/MacroPot-drill_allignment.pdf, cutting it to the size and aligning to the enclosure:

should be

> Start by printing the draft label located here https://github.com/Deftaudio/MacroPot/blob/master/Acrylic%20panels/MacroPot-drill_allignment.pdf, cutting it to the size and aligning to the enclosure:

There are similar issues on Pg7 and 9

Would a PR turning that into Markdown replacing the Google docs location be accepted?

Deftaudio, 2019-10-04:
Thanks a lot, got all the links fixed. I wrote the guide before I published a git, so thanks again.
I don't mind Markdown at all, it was just simpler to me to write Google Docs from mobile devices. There is also PDF version that's compiled: https://github.com/Deftaudio/MacroPot/blob/master/Assembly/MacroPot%20Assembly%20Guide.pdf
Basically, Doc version supposed to be a working doc only, while that one is ready version.

Deftaudio, 2019-10-04:
Also, as you're assembling now, I dropped a change to FW to sync LED to MIDI clock.
https://www.instagram.com/p/B2yJsSPggfu/

Cabalist, 2019-10-04:
That's great thanks!

Closed 2019-10-04.

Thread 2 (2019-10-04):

Template and box corners

Cabalist, 2019-10-04:
Hey there,

I thought I should just give you (and future kit builders) a heads up that the drilling for the template can be quite difficult.   I've made a a mess of the provided box and wanted to document how.

Currently the printed template has the four threaded holes to hold the acrylic top in the corners of the aluminum box.  The box I received also had  4 preexisting threaded holes in the other side.   The interfered with the template and caused the drill bit to shift.   I doubt this would have been a problem with a small drill press but I was drilling these by hand.

I think this could be fixed by moving the acrylic supports in from the corners so that they don't overlap the existing holes.   It would also probably be worthwhile to mark some median lines on the template to ensure alignment.

If others are looking for this box it is a 1590A and available from all the usual places.  There are a bunch of pre-painted ones out there as well.  :)

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

Deftaudio, 2019-10-04:
Thank you for a heads up on that. 1590A is in the BOM list, just right here: https://docs.google.com/spreadsheets/d/15D16pYKxWzvwlihMUm6H49rWIW-DiubtF_ozgL0KMLI/edit?usp=sharing
Might be good idea to put painted versions too.
But the main problem, that's seen on the photos too is rounded corners and all lines which vary from one unit to another. I'd expect because they were polished manually. That's why I had to reduce the size of the acrylic panel, so it goes on the flat surface only. As a result of that corner holes moved slightly to the center which made them offset to the enclosure back holes. If I move acrylic holes to match enclosure holes, I afraid it will be to thin on the corner which is not good either. Anyway, experiment, let me know and propose any changes that can make it better.

Cabalist, 2019-10-04:
No worries.   I didn't see that number on the BOM just an eBay listing.  :)

I think you are right that the there isn't a way to line up with the existing corner holes but I think if the holes are brought in closer to the center by another 5 or 6mm they won't interfere with the supports.

Deftaudio, 2019-10-04:
Closer to the center? This is a nice idea. Then the only problem is the length of the screws, so they won't interfere with a PCB then.

Closed 2023-02-07.

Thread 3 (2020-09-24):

LED footprint on the PCB is backwards

mymaestro, 2020-09-24:
I think the instructions and the screen on the PCB has the LED backwards. Please double-check it.

Deftaudio, 2020-09-24:
Please, refer to instructions and a video guide.

Closed 2023-02-07.

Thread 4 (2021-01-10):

Symbol and Footprint for Encoder?

m-r-m-s, 2021-01-10:
Hi,

Is the Bourns switch encoder symbol and footprint available a custom one you made or is that available somewhere else?

I haven't been able to track it down yet. Looks like I might be able to download the symbol from mouser but I don't have a windows based computer at the moment. Thanks!

Deftaudio, 2021-01-11:
Just design one yourself. This is not difficult. I'm using KiCad for this project and I uploaded my own in a files section: https://github.com/Deftaudio/MacroPot/tree/master/Schematics/Footprints

m-r-m-s, 2021-01-11:
Ok, thank you. I am new to kiCad so I really appreciate you sharing the footprint and will take on the challenge of designing one myself =)

Closed 2021-01-11.

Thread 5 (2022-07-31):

USB host

Nek, 2022-07-31:
Is it possible and, if it is ,how hard is it to add USB controller host functionality to MacroPot?

Deftaudio, 2022-07-31:
Hi, MacroPot is based on Teensy 3.2 that doesn't have USB Host functionality.

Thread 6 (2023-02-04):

Arduino file settings

machinehistories, 2023-02-04:
First off I am glad I finally built your device it’s a very smart thing and so well documented. In your example arduino file you have all of the macro settings commented out. If I uncomment those lines and upload the file those settings don’t appear to load. For example none of the names are displayed on the Oled. Can you tell me what to do to add macro settings using the commented code in arduino or is the only option to use sysex. Thanks

Deftaudio, 2023-02-06:
Hi Jason, that's easy to sort out. You don't need to change the code. Just after initial programming load the default macro set. It's here in scripts https://github.com/Deftaudio/MacroPot/tree/master/SysEx%20scripts and the details are in the video guide.

machinehistories, 2023-02-07:
I got it working well with sysex as shown in the video but if I wanted to
use arduino instead of sysex is that possible? It looks like you have a
section of code commented out that appears to set the button and
controllers but when I uncommented it and uploaded the code it didn't
appear to take the settings from the arduino code. I was just curious. It's
a very neat device.

On Mon, Feb 6, 2023 at 11:01 AM Andrei Kudryavtsev ***@***.***>
wrote:

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

Deftaudio, 2023-02-07:
I see. Those line were left from some development where I didn't want to touch EPROM memory each time and kept it in constants for the simplicity. Since that time many code has been added, including reading and writing to EPROM, so I'm not surprised that it's no longer working. It's better to program it through SysEx, it updates all data structures in EPROM.

machinehistories, 2023-02-07:
Gotcha. thanks. I made a spreadsheet to automate the generation of the
sysex argument. It might be useful to others to help get their arguments
formatted. Feel free to share it. thanks
 [image: macro.jpg]

On Mon, Feb 6, 2023 at 5:36 PM Andrei Kudryavtsev ***@***.***>
wrote:

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

Deftaudio, 2023-02-07:
Please, share. Another user made an attempt for MAX patch, however I found it broken and don't have MAX license to fix it.

machinehistories, 2023-02-07:
I uploaded it to a repository since it didn't seem to keep the attachment in my previous response.[https://github.com/machinehistories/macropt_sysex_sheet](url)

Deftaudio, 2023-02-07:
Thank you, added to the SysEx Scripts directory.

machinehistories, 2023-02-07:
that's pretty cool. thanks

On Tue, Feb 7, 2023 at 12:50 PM Andrei Kudryavtsev ***@***.***>
wrote:

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

machinehistories, 2024-02-14:
I am trying to add 6 controllers. I want to be able to have one mixer
channel on the tx-6 raise in volume and the others lower. You can cc
control the faders. I tried modifying the arduino code and then adding a
macro with 6 controllers. When I check the midi output controller 1 is
double the values output on controllers 3-6 even though they should all be
the same. Controller 2 is not outputting a message but at a certain point
controller one stops outputting a value and controller 2 starts outputting
but then controller 1 no longer outputs. I'm sure you can tell me what I
did wrong. I'm not a programmer and aside from changing the obvious
settings in the code like the max number of controllers from 5 to 6 I'm not
sure what else I should change. I'd really appreciate your help. Also what
curve value do you recommend for volume control.  thanks

On Tue, Feb 7, 2023 at 1:31 PM Andrei Kudryavtsev ***@***.***>
wrote:

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

machinehistories, 2024-02-15:
I think I got it working but I had to change the max number of macros to 8.
Is this because of the eprom memory limit?

On Tue, Feb 13, 2024 at 11:26 PM jason pilarski ***@***.***>
wrote:

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

Deftaudio, 2024-02-15:
I'm sorry, it's been years since I touched that code.
You may have just a dirty EPROM. When you increased a max macros #, it tries to read it from EPROM at power on.
it would be best to save it first, restart and only after that try for the first time.

machinehistories, 2024-02-15:
I think it's working, thanks for your help.

On Thu, Feb 15, 2024 at 12:36 PM Andrei Kudryavtsev <
***@***.***> wrote:

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

Closed 2023-02-07.

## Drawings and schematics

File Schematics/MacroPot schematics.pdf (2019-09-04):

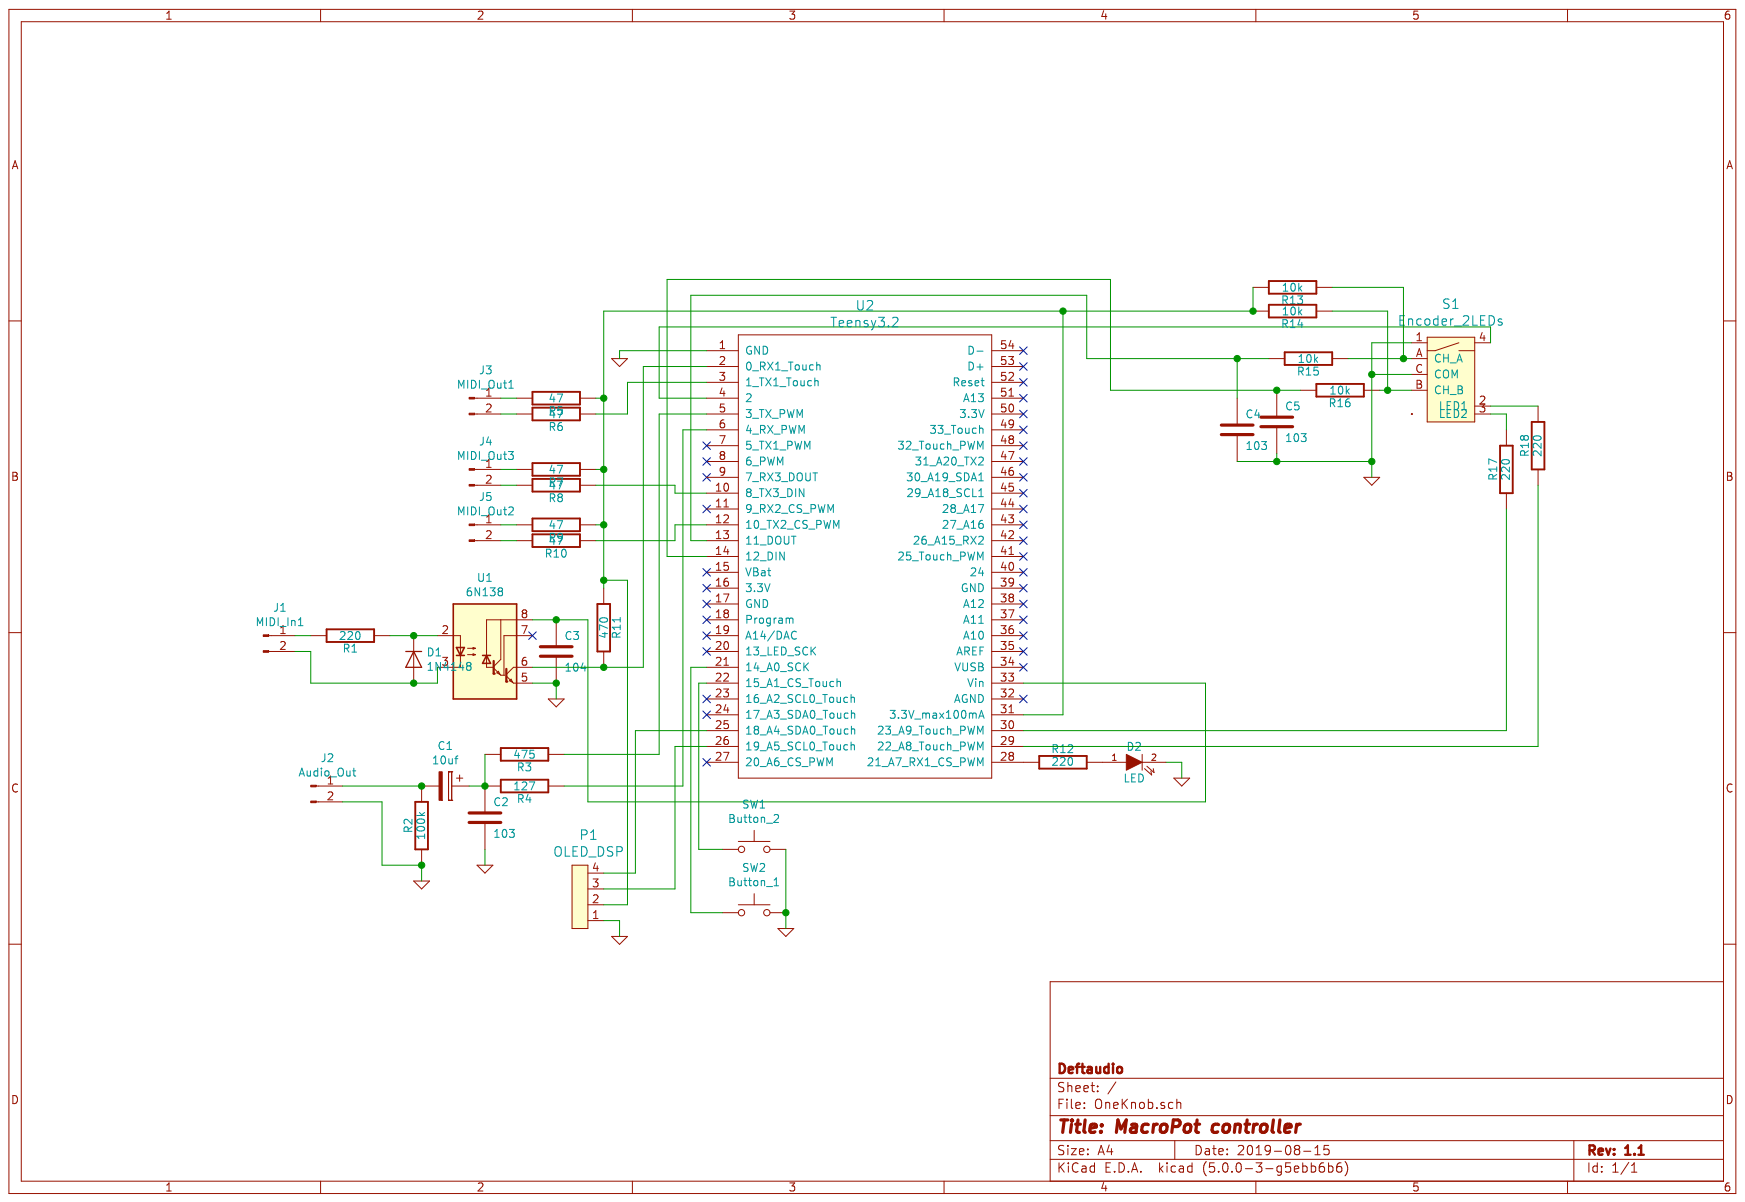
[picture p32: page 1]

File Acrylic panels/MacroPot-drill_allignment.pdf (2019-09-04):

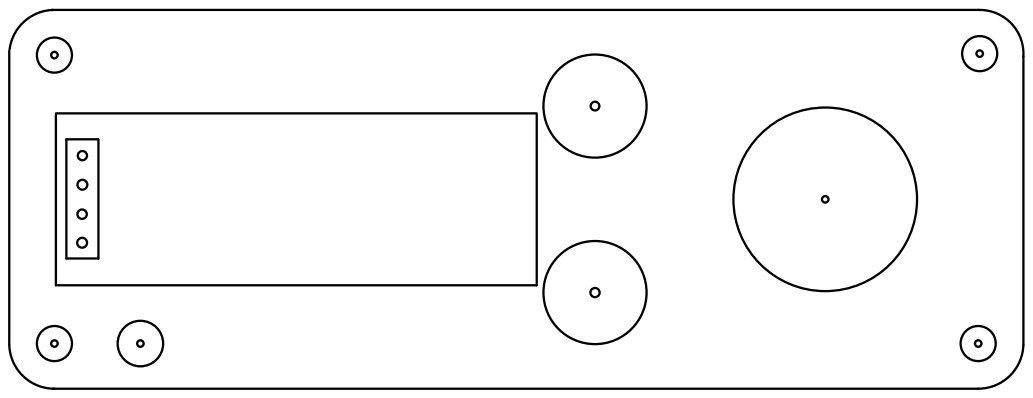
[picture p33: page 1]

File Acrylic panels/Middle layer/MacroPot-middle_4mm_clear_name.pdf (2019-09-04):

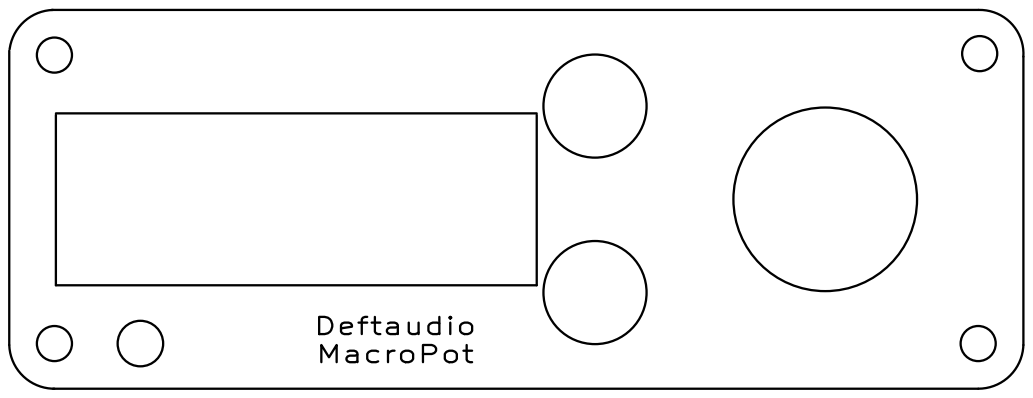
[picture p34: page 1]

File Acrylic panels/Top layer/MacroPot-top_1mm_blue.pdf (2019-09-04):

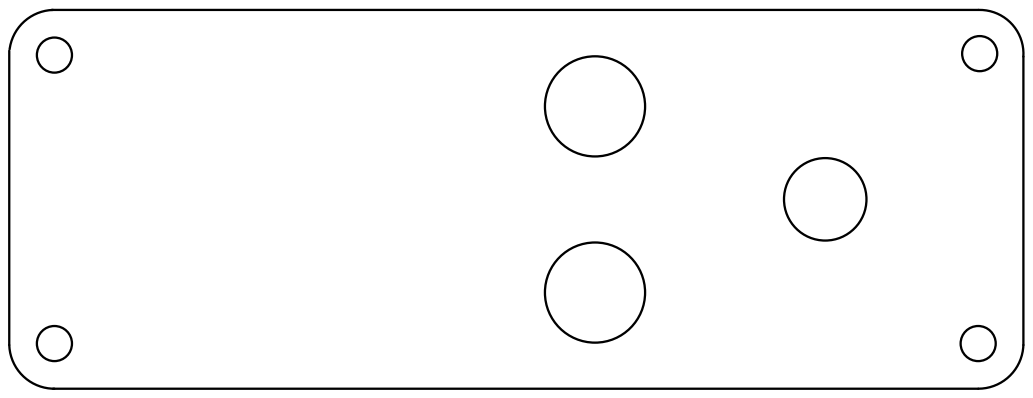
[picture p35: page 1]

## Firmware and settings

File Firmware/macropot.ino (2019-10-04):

#include <SPI.h>
#include <Wire.h>
#include <Adafruit_GFX.h>
#include <Adafruit_SSD1306.h>
#include <MIDI.h>
#include <Audio.h>

#define OLED_RESET 4
Adafruit_SSD1306 display(OLED_RESET);

#include <Bounce.h>
#include <EEPROM.h>
#include <Encoder.h>

//MIDI port set up
MIDI_CREATE_INSTANCE(HardwareSerial, Serial1, MIDI1);
MIDI_CREATE_INSTANCE(HardwareSerial, Serial2, MIDI2);
MIDI_CREATE_INSTANCE(HardwareSerial, Serial3, MIDI3);

// A variable to know how long the LED has been turned on
elapsedMillis ledOnMillis;

int i;

//Basic parameters
const int ledPin = 21;
int blinkrate=0;
bool activity = false;
bool dataintegrity = false;
const int TotalMacro=10;

//encoder button pin
const int Enc_button = 2;
Bounce button0 = Bounce(Enc_button,5);

//encoder acceleration slope

int height = 4; //height
float slope = 0.3; //slope


unsigned long last_time;
unsigned long delta_time = 0;
unsigned long time_now = 0;
unsigned long encoderSlope=1;

//Audio
// GUItool: begin automatically generated code
AudioSynthSimpleDrum     drum1;          //xy=322,378
AudioOutputAnalog        dac1;           //xy=569,381
AudioConnection          patchCord1(drum1, dac1);
// GUItool: end automatically generated code


//two buttons
const int Assign_button_1 = 14;
const int Assign_button_2 = 15;
Bounce button1 = Bounce(Assign_button_1,5);
Bounce button2 = Bounce(Assign_button_2,5);


//Encoder config
const int encoder0PinA = 12;
const int encoder0PinB = 11;
Encoder mainEnc(encoder0PinA, encoder0PinB);
//long encoderPosition  = -999;
long newEncoderReading = -999;
int maxEncoder = 512; //512
int maxValue = 127;
int encoderAcc = 10;
int progress = 0;
int val = 0;
const int PWMled1 = 22;
const int PWMled2 = 23;

//static uint8_t sysex[6] = {0x7D, 0x01, 0x10, 0x0e, 0x0f, 0x01};

struct Button{
  uint8_t USBport=1;          //USB port # to send a data out, zero means don't send
  uint8_t MIDIport=1;         //HW MIDI port # to send a data out, zero means don't send
  uint8_t type=0;             //1=CC, 2=Note
  uint8_t number;             //CC# or Note#
  uint8_t channel=1;          //MIDI Channel
  uint8_t value;              //Velocity for Note ON messages or CC value
  boolean push;               //true=push, false=toggle for NOTE ON
  boolean toggled = false;
};
struct Controller{
  uint8_t USBport=1;          //USB port # to send a data out, zero means don't send
  uint8_t MIDIport=1;         //HW MIDI port # to send a data out, zero means don't send
  uint8_t type=0;             //1=CC, 2=Note, 3=Program Change, 4=NRPN, 5=SynclavierMODE(can be the ONLY in a macro)
  uint8_t channel=1;          //MIDI Channel
  uint8_t number;             //CC# or Note# or Program#
  uint8_t lowvalue;           //Low Value for CC, main value for Note
  uint8_t highvalue;          //High Value for CC, ignored Note
  uint8_t velocity;           //Velocity for Note ON messages
  uint8_t mapstart;           //Low Value for CC, main value for Note
  uint8_t mapend;             //High Value for CC, ignored Note
  int     deviation=0;        //For creating curves for CC messages deviation -100 to 100.
  boolean toggled=false;      //For Note or Program Change toggled tracking
 
};

struct MacroPot{
  char name[8] = {'M', 'a', 'c', 'r', 'o', ' ', 'X', '\0'};   //Display name
  struct Button Button;
  struct Controller Controller[5];                      // 5 controllers simultaniously to send
  uint8_t MidiMerge = 0;                                // need to define MIDI IN to MERGE OUT 1-3, 0 means no merge.
  long encoderPosition = 0;
};

struct MacroPot MacroPot[TotalMacro];
uint8_t CurrentMacro=0;



void myClock() {
  digitalWrite(ledPin, LOW); // Any Note-On turns on LED
  analogWrite(PWMled1, 0);
  blinkrate++;
  if (blinkrate >= 4) {
    blinkrate=-16;
    digitalWrite(ledPin, HIGH);
    analogWrite(PWMled1, 255);
  }

  //Audio Output on clock Test Example here:
  drum1.noteOn();

}

void EpromSave() {
  double addr=0;
  for (i = 0; i < TotalMacro; i++) {
    EEPROM.put(addr, MacroPot[i]);
    addr=addr+sizeof(MacroPot[i]);  
  }
  EEPROM.put(addr+sizeof(MacroPot[TotalMacro]), CurrentMacro);
   
}

void EpromLoad() {
  double addr=0;
  for (i = 0; i < TotalMacro; i++) {
    EEPROM.get(addr, MacroPot[i]);
    addr=addr+sizeof(MacroPot[i]);  
  }
  EEPROM.get(addr+sizeof(MacroPot[TotalMacro]), CurrentMacro);    

}


void setup() {
  Serial.begin(115200);
  //1 MIDI rate
  //Serial.begin(31250);
  pinMode(Enc_button, INPUT_PULLUP);
  pinMode(Assign_button_1, INPUT_PULLUP);
  pinMode(Assign_button_2, INPUT_PULLUP);
  
  pinMode(ledPin, OUTPUT);
  pinMode(PWMled1, OUTPUT);
  pinMode(PWMled2, OUTPUT);
  analogWrite(PWMled1,0);
  analogWrite(PWMled2,0);
/*for non pull up encoder
  pinMode (encoder0PinA, INPUT);
  pinMode (encoder0PinB, INPUT);
  pinMode(encoder0PinA, INPUT_PULLUP);
  pinMode(encoder0PinB, INPUT_PULLUP);  
*/

  //Audio
  AudioMemory(10);
  AudioNoInterrupts();
  drum1.frequency(60);
  drum1.length(1500);
  drum1.secondMix(0.0);
  drum1.pitchMod(0.55);
  AudioInterrupts();
 
  //MIDI
  MIDI1.begin(MIDI_CHANNEL_OMNI);
  MIDI2.begin(MIDI_CHANNEL_OMNI);
  MIDI3.begin(MIDI_CHANNEL_OMNI);
  MIDI1.turnThruOff();
  MIDI2.turnThruOff();
  MIDI3.turnThruOff();

  
  usbMIDI.setHandleClock(myClock);
   
  display.begin(SSD1306_SWITCHCAPVCC, 0x3C); 
  delay(5);
 
 //display init, not required for "good" OLED
 //   delay(3000); 
  


  // Clear the buffer.
  display.clearDisplay();

  // text display tests
  display.setTextSize(2);
  display.setTextColor(WHITE);
  display.setCursor(0,0);
  display.println("Deftaudio");
  
 // display.setTextColor(BLACK, WHITE);
 // display.setCursor(90,0);
 // display.print("127");

 // display.fillRect(0, 17, display.width(), display.height()-17, WHITE);
  display.drawRect(0, 17, display.width(), display.height()-17, WHITE);
  display.display();
  delay(100);

//export all EPROM data
 // usbMIDI.sendSysEx(6, sysex);

//version LED blink
  analogWrite(PWMled1, 255);
  digitalWriteFast(ledPin, HIGH);
  delay(200);
  digitalWriteFast(ledPin, LOW);
  analogWrite(PWMled1, 0);
  button1.update();
  button2.update();
  

/*
//TEST DEFINE Macro:
  for (i = 0; i <= 10; i++) {
    MacroPot[i].name[6] = '1'+i; }

CurrentMacro=0;
MacroPot[CurrentMacro].name[0] = {'T'};
MacroPot[CurrentMacro].name[1] = {'e'};
MacroPot[CurrentMacro].name[2] = {'s'};
MacroPot[CurrentMacro].name[3] = {'t'};
MacroPot[CurrentMacro].name[4] = {':'};
MacroPot[CurrentMacro].name[5] = {' '};
MacroPot[CurrentMacro].name[6] = {'1'};
MacroPot[CurrentMacro].name[7] = {'\0'};
MacroPot[CurrentMacro].Button.USBport=1;
MacroPot[CurrentMacro].Button.MIDIport=1;
MacroPot[CurrentMacro].Button.type=2;
MacroPot[CurrentMacro].Button.channel=1;
MacroPot[CurrentMacro].Button.number=64;
MacroPot[CurrentMacro].Button.value=127;
MacroPot[CurrentMacro].Button.push=false;

MacroPot[CurrentMacro].Controller[0].USBport=1;
MacroPot[CurrentMacro].Controller[0].MIDIport=1;
MacroPot[CurrentMacro].Controller[0].type=1;
MacroPot[CurrentMacro].Controller[0].channel=1;
MacroPot[CurrentMacro].Controller[0].number=44;
MacroPot[CurrentMacro].Controller[0].lowvalue=0;
MacroPot[CurrentMacro].Controller[0].highvalue=127;
MacroPot[CurrentMacro].Controller[0].mapstart=0;
MacroPot[CurrentMacro].Controller[0].mapend=127;
MacroPot[CurrentMacro].Controller[0].deviation=0;

MacroPot[CurrentMacro].Controller[1].USBport=2;
MacroPot[CurrentMacro].Controller[1].MIDIport=1;
MacroPot[CurrentMacro].Controller[1].type=1;
MacroPot[CurrentMacro].Controller[1].channel=2;
MacroPot[CurrentMacro].Controller[1].number=45;
MacroPot[CurrentMacro].Controller[1].lowvalue=0;
MacroPot[CurrentMacro].Controller[1].highvalue=127;
MacroPot[CurrentMacro].Controller[1].mapstart=64;
MacroPot[CurrentMacro].Controller[1].mapend=127;
MacroPot[CurrentMacro].Controller[1].deviation=0;

CurrentMacro=1;
MacroPot[CurrentMacro].name[0] = {'S'};
MacroPot[CurrentMacro].name[1] = {'e'};
MacroPot[CurrentMacro].name[2] = {'s'};
MacroPot[CurrentMacro].name[3] = {'t'};
MacroPot[CurrentMacro].name[4] = {':'};
MacroPot[CurrentMacro].name[5] = {' '};
MacroPot[CurrentMacro].name[6] = {'2'};
MacroPot[CurrentMacro].name[7] = {'\0'};

MacroPot[CurrentMacro].Controller[0].USBport=2;
MacroPot[CurrentMacro].Controller[0].MIDIport=1;
MacroPot[CurrentMacro].Controller[0].type=5;
MacroPot[CurrentMacro].Controller[0].channel=2;

CurrentMacro=2;
MacroPot[CurrentMacro].name[0] = {'T'};
MacroPot[CurrentMacro].name[1] = {'e'};
MacroPot[CurrentMacro].name[2] = {'s'};
MacroPot[CurrentMacro].name[3] = {'t'};
MacroPot[CurrentMacro].name[4] = {':'};
MacroPot[CurrentMacro].name[5] = {' '};
MacroPot[CurrentMacro].name[6] = {'3'};
MacroPot[CurrentMacro].name[7] = {'\0'};

CurrentMacro=3;
MacroPot[CurrentMacro].name[0] = {'T'};
MacroPot[CurrentMacro].name[1] = {'e'};
MacroPot[CurrentMacro].name[2] = {'s'};
MacroPot[CurrentMacro].name[3] = {'t'};
MacroPot[CurrentMacro].name[4] = {':'};
MacroPot[CurrentMacro].name[5] = {' '};
MacroPot[CurrentMacro].name[6] = {'4'};
MacroPot[CurrentMacro].name[7] = {'\0'};

CurrentMacro=4;
MacroPot[CurrentMacro].name[0] = {'T'};
MacroPot[CurrentMacro].name[1] = {'e'};
MacroPot[CurrentMacro].name[2] = {'s'};
MacroPot[CurrentMacro].name[3] = {'t'};
MacroPot[CurrentMacro].name[4] = {':'};
MacroPot[CurrentMacro].name[5] = {' '};
MacroPot[CurrentMacro].name[6] = {'5'};
MacroPot[CurrentMacro].name[7] = {'\0'};
*/

// Zero Macro state
CurrentMacro=0;

//EPROM LOAD
EpromLoad();


//INIT button UP/DOWN code
checkButtons();

//INIT check encoder button
checkEncButton();


//initial display macros name
DisplayTitleUpdate();

}

void DisplayTitleUpdate(){
  display.clearDisplay();  
  display.setTextSize(2);
  display.setTextColor(WHITE);
  display.setCursor(0,0);
  display.println(String(MacroPot[CurrentMacro].name));
  display.drawRect(0, 17, display.width(), display.height()-17, WHITE);

  display.display();
  
 // delay(1000);
}

void SysexMode(){
  //Special Sysex MODE
  display.clearDisplay();
  display.setCursor(0,0);
  display.setTextColor(BLACK, WHITE);
  display.print("Sysex Mod");
  display.display();
  button1.update();
  button2.update();

  //WAIT HERE:
  while(!button1.fallingEdge())
  {
    button1.update();

  if (usbMIDI.read()) {
    byte type = usbMIDI.getType();
    //byte channel = usbMIDI.getChannel();
    //byte data1 = usbMIDI.getData1();
    //byte data2 = usbMIDI.getData2();
    //byte cable = usbMIDI.getCable();

    if (type == usbMIDI.SystemExclusive) {

      // SysEx messages are special.  The message length is given in data1 & data2
      //unsigned int SysExLength = data1 + data2 * 256;
        
      // Unpack SysEx
      byte * sysbytes = usbMIDI.getSysExArray();
      
     /*
        for (i = 0; i <= 16; i++) { 
        display.clearDisplay();
        display.setTextColor(WHITE, BLACK);
        display.setCursor(40,18);
        display.print("         ");
        display.setCursor(40,18);
        display.print(i);
        display.print(": ");
        display.print(sysbytes[i], HEX);
        display.display();
        delay (1000); 
        }
      */
      // Check for SysEx  config message
      if (sysbytes[0] == 0xf0 && sysbytes[1] == 0x7d) { // check start f0 and ID 7D.
           
        //CurrentMacro = sysbytes[2];
        switch (sysbytes[3]) {
          //Main parameters
          case 100:
            MacroPot[sysbytes[2]].name[0] = sysbytes[4];
            MacroPot[sysbytes[2]].name[1] = sysbytes[5];
            MacroPot[sysbytes[2]].name[2] = sysbytes[6];
            MacroPot[sysbytes[2]].name[3] = sysbytes[7];
            MacroPot[sysbytes[2]].name[4] = sysbytes[8];
            MacroPot[sysbytes[2]].name[5] = sysbytes[9];
            MacroPot[sysbytes[2]].name[6] = sysbytes[10];
            MacroPot[sysbytes[2]].name[7] = {'\0'};
            MacroPot[sysbytes[2]].MidiMerge = sysbytes[11];

            if (sysbytes[12] == 0x7f) { dataintegrity=true; } // check the last byte
            display.clearDisplay();
            display.setTextColor(WHITE, BLACK);
            display.setCursor(0,0);
            display.println("OK: UP for exit");
            display.display();
            break;
            
          //Button configuration
          case 0:
            MacroPot[sysbytes[2]].Button.USBport=sysbytes[4];
            MacroPot[sysbytes[2]].Button.MIDIport=sysbytes[5];
            MacroPot[sysbytes[2]].Button.type=sysbytes[6];
            MacroPot[sysbytes[2]].Button.channel=sysbytes[7];
            MacroPot[sysbytes[2]].Button.number=sysbytes[8];
            MacroPot[sysbytes[2]].Button.value=sysbytes[9];
            MacroPot[sysbytes[2]].Button.push=sysbytes[10];
            
            if (sysbytes[11] == 0x7f) { dataintegrity=true; } // check the last byte
            display.clearDisplay();
            display.setTextColor(WHITE, BLACK);
            display.setCursor(0,0);
            display.println("OK: UP for exit");
            display.display();
            break;
            
          //Controller configuration
          case 1:
          case 2:
          case 3:
          case 4:
          case 5:
            MacroPot[sysbytes[2]].Controller[sysbytes[3]-1].USBport=sysbytes[4];
            MacroPot[sysbytes[2]].Controller[sysbytes[3]-1].MIDIport=sysbytes[5];
            MacroPot[sysbytes[2]].Controller[sysbytes[3]-1].type=sysbytes[6];
            MacroPot[sysbytes[2]].Controller[sysbytes[3]-1].channel=sysbytes[7];
            MacroPot[sysbytes[2]].Controller[sysbytes[3]-1].number=sysbytes[8];
            MacroPot[sysbytes[2]].Controller[sysbytes[3]-1].lowvalue=sysbytes[9];
            MacroPot[sysbytes[2]].Controller[sysbytes[3]-1].highvalue=sysbytes[10];
            MacroPot[sysbytes[2]].Controller[sysbytes[3]-1].mapstart=sysbytes[11];
            MacroPot[sysbytes[2]].Controller[sysbytes[3]-1].mapend=sysbytes[12];
            MacroPot[sysbytes[2]].Controller[sysbytes[3]-1].deviation=sysbytes[13];
            MacroPot[sysbytes[2]].Controller[sysbytes[3]-1].velocity=sysbytes[14];
            
            if (sysbytes[15] == 0x7f) { dataintegrity=true; } // check the last byte
            display.clearDisplay();
            display.setTextColor(WHITE, BLACK);
            display.setCursor(0,0);
            display.println("OK: UP for exit");
            //display.println(MacroPot[sysbytes[2]].Controller[sysbytes[3]-1].deviation);
            display.display();           
            break;
        }
      } 
     }
      
  
  
  }
 }   
  display.clearDisplay();
  
  //Save ALL
  if (dataintegrity) {
   EpromSave();   
   }
 
  DisplayTitleUpdate();
  UpdateState();
  activity = true;
}

void DisplaySynclavier(){
  display.clearDisplay();
  display.setCursor(0,0);
  display.setTextColor(BLACK, WHITE);
  display.print("Synclavier");
  display.display();
  mainEnc.write(MacroPot[CurrentMacro].encoderPosition);
  encoderAcc=0;
}
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
void loop() {
  activity = false;

// HARDWARE MIDI IN FLOW
  if (MIDI1.read()) {
    // get a MIDI IN1 (Serial) message
    byte type = MIDI1.getType();
    byte channel = MIDI1.getChannel();
    byte data1 = MIDI1.getData1();
    byte data2 = MIDI1.getData2();

    // forward the message to USB MIDI virtual cable #0
    if (type != midi::SystemExclusive) {
      // Normal messages, simply give the data to the usbMIDI.send()
      usbMIDI.send(type, data1, data2, channel, 0);
      usbMIDI.send_now();
      
      if (bitRead(MacroPot[CurrentMacro].MidiMerge,0)==true) {
        MIDI1.send(type, data1, data2, channel);        
      }
      if (bitRead(MacroPot[CurrentMacro].MidiMerge,1)==true) {
        MIDI2.send(type, data1, data2, channel);
        
      }
      if (bitRead(MacroPot[CurrentMacro].MidiMerge,2)==true) {
        MIDI3.send(type, data1, data2, channel);    
      }

    } else {
      // SysEx messages are special.  The message length is given in data1 & data2
      unsigned int SysExLength = data1 + data2 * 256;
      usbMIDI.sendSysEx(SysExLength, MIDI1.getSysExArray(), true, 0);
      usbMIDI.send_now();
      
      if (bitRead(MacroPot[CurrentMacro].MidiMerge,0)==true) {
        MIDI1.sendSysEx(SysExLength, MIDI1.getSysExArray(), true);
        
      }
      if (bitRead(MacroPot[CurrentMacro].MidiMerge,1)==true) {
        MIDI2.sendSysEx(SysExLength, MIDI1.getSysExArray(), true);
        
      }
      if (bitRead(MacroPot[CurrentMacro].MidiMerge,2)==true) {
        MIDI3.sendSysEx(SysExLength, MIDI1.getSysExArray(), true);
        
      } 
    }
    activity = true;
  }

  if (MIDI2.read()) {
    // get a MIDI IN2 (Serial) message
    byte type = MIDI2.getType();
    byte channel = MIDI2.getChannel();
    byte data1 = MIDI2.getData1();
    byte data2 = MIDI2.getData2();

    // forward the message to USB MIDI virtual cable #1
    if (type != midi::SystemExclusive) {
      // Normal messages, simply give the data to the usbMIDI.send()
      usbMIDI.send(type, data1, data2, channel, 1);
      usbMIDI.send_now();
    } else {
      // SysEx messages are special.  The message length is given in data1 & data2
      unsigned int SysExLength = data1 + data2 * 256;
      usbMIDI.sendSysEx(SysExLength, MIDI1.getSysExArray(), true, 1);
      usbMIDI.send_now();
    }
    activity = true;
  }

  if (MIDI3.read()) {
    // get a MIDI IN1 (Serial) message
    byte type = MIDI3.getType();
    byte channel = MIDI3.getChannel();
    byte data1 = MIDI3.getData1();
    byte data2 = MIDI3.getData2();

    // forward the message to USB MIDI virtual cable #0
    if (type != midi::SystemExclusive) {
      // Normal messages, simply give the data to the usbMIDI.send()
      usbMIDI.send(type, data1, data2, channel, 2);
      usbMIDI.send_now();
    } else {
      // SysEx messages are special.  The message length is given in data1 & data2
      unsigned int SysExLength = data1 + data2 * 256;
      usbMIDI.sendSysEx(SysExLength, MIDI1.getSysExArray(), true, 2);
      usbMIDI.send_now();
    }
    activity = true;
  }

//END OF HARDWARE FLOW


// USB FLOW: coming out of USB
if (usbMIDI.read()) {
    // get the USB MIDI message, defined by these 5 numbers (except SysEX)
    byte type = usbMIDI.getType();
    byte channel = usbMIDI.getChannel();
    byte data1 = usbMIDI.getData1();
    byte data2 = usbMIDI.getData2();
    byte cable = usbMIDI.getCable();

    // forward this message to 1 of the 3 Serial MIDI OUT ports
    if (type != usbMIDI.SystemExclusive) {
      // Normal messages, first we must convert usbMIDI's type (an ordinary
      // byte) to the MIDI library's special MidiType.
      midi::MidiType mtype = (midi::MidiType)type;

      // Then simply give the data to the MIDI library send()
      switch (cable) {
        case 0:
          MIDI1.send(mtype, data1, data2, channel);
          break;
        case 1:
          MIDI2.send(mtype, data1, data2, channel);
          break;
        case 2:
          MIDI3.send(mtype, data1, data2, channel);
          break;
      }

    } else {
      // SysEx messages are special.  The message length is given in data1 & data2
      unsigned int SysExLength = data1 + data2 * 256;
        
        // Unpack SysEx
        byte * sysbytes = usbMIDI.getSysExArray();
 
      switch (cable) {
        case 0:
          MIDI1.sendSysEx(SysExLength, sysbytes, true);
          break;
        case 1:
          MIDI2.sendSysEx(SysExLength, sysbytes, true);
          break;
        case 2:
          MIDI3.sendSysEx(SysExLength, sysbytes, true);
          break;
      }
        
    }
    activity = true;
  }


//button UP/DOWN code
checkButtons();

//check encoder button
checkEncButton();




//encoder read and min/max values adjust
  newEncoderReading = mainEnc.read();

 if (MacroPot[CurrentMacro].Controller[0].type!=5) { 
  if (newEncoderReading > maxEncoder) {
    newEncoderReading = maxEncoder;
    mainEnc.write(maxEncoder);   
  }

  if (newEncoderReading < 0) {
    newEncoderReading = 0;
    mainEnc.write(0);    
  }
 }

    
//update on encoder change
  if (newEncoderReading != MacroPot[CurrentMacro].encoderPosition) {

  //encoder acceleration calc
    time_now = millis();
    delta_time = time_now - last_time;
    if (delta_time < 27) {
    encoderSlope = int(0.3 * (27 - delta_time) + 1);
    }
    last_time = time_now;
    encoderAcc = (newEncoderReading - MacroPot[CurrentMacro].encoderPosition) * encoderSlope;
     
    if ((newEncoderReading > MacroPot[CurrentMacro].encoderPosition)&&(newEncoderReading + encoderAcc < maxEncoder)){
      MacroPot[CurrentMacro].encoderPosition = newEncoderReading + encoderAcc;
      mainEnc.write(MacroPot[CurrentMacro].encoderPosition);
    }
    else if ((newEncoderReading < MacroPot[CurrentMacro].encoderPosition)&&(newEncoderReading + encoderAcc > 0)){
      MacroPot[CurrentMacro].encoderPosition = newEncoderReading + encoderAcc;
      mainEnc.write(MacroPot[CurrentMacro].encoderPosition);
    }
    else 
      MacroPot[CurrentMacro].encoderPosition = newEncoderReading;

    if (MacroPot[CurrentMacro].Controller[0].type!=5) {
     UpdateState();
          }

    EncoderProcessing();
  }


  // blink the LED when any activity has happened
  if (activity) {
    digitalWriteFast(ledPin, HIGH); // LED on
    ledOnMillis = 0;
  }
  if (ledOnMillis > 15) {
    digitalWriteFast(ledPin, LOW);  // LED off
  } 
  
 // Clean up for Synclavier mode - autozero function.
  if (ledOnMillis > 200 && MacroPot[CurrentMacro].Controller[0].type==5 && MacroPot[CurrentMacro].Controller[0].toggled==true) {
    encoderAcc=0;
    EncoderProcessing(); 
    MacroPot[CurrentMacro].Controller[0].toggled=false;
    analogWrite(PWMled2, 0);
  }

  
  delayMicroseconds(50); // limits message frequency
}

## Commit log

2019-09-04 Rev 1.0 spec release
    [MacroPot-middle_4mm_clear_name.dxf, MacroPot-top_1mm_blue.dxf]
2019-09-05 added Arduino sketch sources
2019-10-04 Update MacroPot Assembly Guide.pdf
2023-02-07 Create SysEx Configuration Tool.xlsx
    Added new tool for SysEx configuration. Thank you Jason Pilarski!
    [SysEx Configuration Tool.xlsx]
